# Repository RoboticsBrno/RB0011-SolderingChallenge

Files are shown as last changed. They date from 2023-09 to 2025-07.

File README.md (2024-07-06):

# RB0011 Soldering Challenge

<p align="center">


</p>

Solving the SMD soldering challenge is a great way to learn how to solder SMD components.

<div align="center">
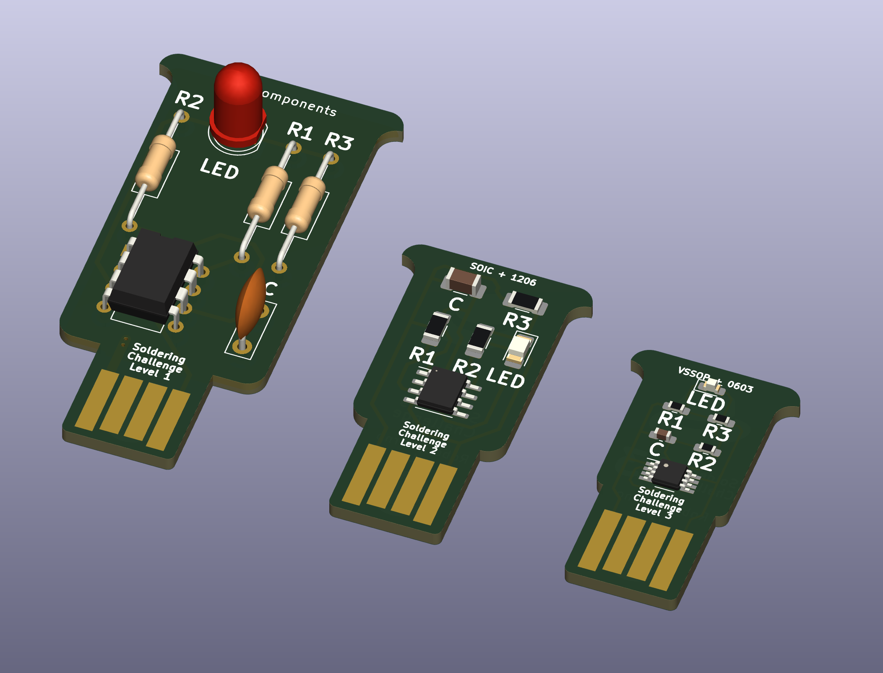
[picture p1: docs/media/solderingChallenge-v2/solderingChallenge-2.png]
    
</div>

[Soldering Instructions](assembly/index.md){ .md-button .md-button--primary }

The challenge is to solder all the components on the PCB in the shortest time possible.

## Levels
- Level 1 - THT components
- Level 2 - SMD 1206 components
- Level 3 - SMD 0603 components
<!-- - Level 4 - SMD 0402 components (PCB is not complete)
- Level 5 - SMD 0201 components (PCB is not complete) -->

If you manage to plug in all the components correctly, the LED will flash at about 2 Hz when plugged into the USB port.

<div align="center">
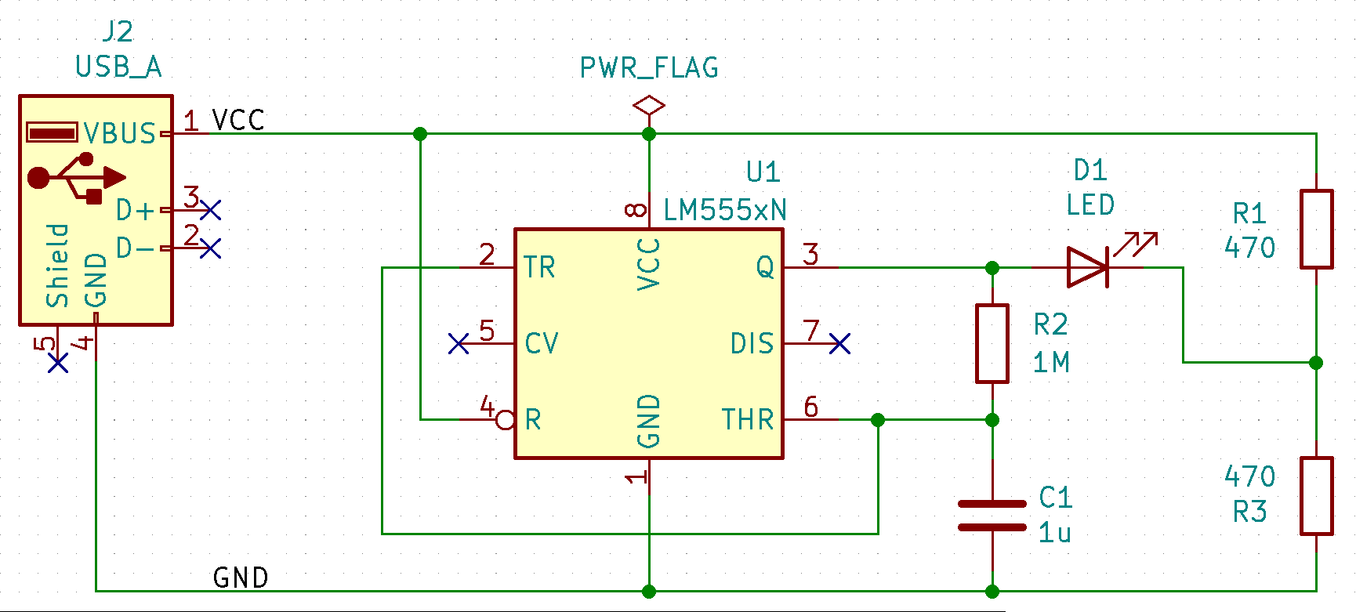
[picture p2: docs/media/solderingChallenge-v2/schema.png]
    
</div>

!!! info "Attention, L2 has swapped resistor R1 and R2"

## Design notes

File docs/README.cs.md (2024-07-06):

# RB0011 Pájecí výzva

<p align="center">


</p>

Pájecí challenge je skvělý způsob jak se naučit pájet SMD součástky.

<div align="center">
    
</div>

[Návod na pájení](assembly/index.md){ .md-button .md-button--primary }

Pájecí výzva spočívá v zapájení všech součástek na DPS v co nejkratším čase.

## Úrovně
- Level 1 - THT součástky
- Level 2 - SMD 1206 součástky
- Level 3 - SMD 0603 součástky
<!-- - Level 4 - SMD 0402 součástky
- Level 5 - SMD 0201 součástky -->

Pokud se ti podaří správně zapájet všechny součástky, tak po zapojení do USB portu začne LED blikat s frekvencí cca 2 Hz.

<div align="center">
    
</div>

!!! info "Pozor, L2 má prohozený rezistor R1 a R2"

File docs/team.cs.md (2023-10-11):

# Kdo za tím stojí

<script src="https://kit.fontawesome.com/5b4ac9752d.js" crossorigin="anonymous"></script>

Robotárna je unikátním spojením technické dílny a volnočasového vzdělávacího centra.
Zasazujeme se o vystavení našich žáků technickým a fyzikálním principům, což umožňuje efektivní tvorbu myšlenkových struktur a pomáhá s jejich rozvojem jak v oblasti techniky, tak v oblasti komunikace.

<div>
	<a href="https://robotickytabor.cz/" target="_blank">
		
	</a>
	<a href="https://robotka.robotickytabor.cz/" target="_blank">
	
	</a>
	<a href="https://roboruka.robotickytabor.cz/" target="_blank">
		
	</a>
</div>

Věříme, že dosažení vysokých cílů je možné skrze práci na mnoha úrovních abstrakce.
V rámci našich projektů si vyvíjíme vlastní mechanické součásti, elektorniku, firmware a software. I přesto jsou projekty koncipovány tak, aby byly přístupné i pro děti a začátečníky.
Naší misí je **vzbuzování zájmu mládeže o pochopení techniky tím, že je vystavujeme pokročilým systémům, které jsou však stále v jejich dosahu**.

Každý rok organizujeme [Robotický tábor](https://robotickytabor.cz/) s mnoha poutavými aktivitami. Programem tábora je také výroba fyzického zařízení, které je třeba smontovat, zapájet a naprogramovat.
Během školního roku naši žáci navštěvují volnočasové kroužky zaměřující se na stavění modelů, mechaniku, elektroniku a programování.
Jsme přesvědčeni, že naše aktivity jsou důležité pro doplnění veřejného vzdělávacího systému v oblasti techniky a poskytnutí mládeži více možností rozvoje.

<!-- <div align="center">
<a href="https://helceletka.cz/robotarna/"><button>Helceletka&nbsp;&nbsp;&nbsp;</button></a>
<a href="https://robotickytabor.cz/"><button>RoboCamp&nbsp;&nbsp;&nbsp;</button></a>
<a href="https://www.instagram.com/_robotarna_/"><button>Instagram&nbsp;&nbsp;&nbsp;</button></a>
<a href="https://www.facebook.com/robotarna"><button>Facebook&nbsp;&nbsp;&nbsp;</button></a>
<a href="https://www.youtube.com/@robotikabrno-robotarnaasps2392"><button>YouTube&nbsp;&nbsp;&nbsp;</button></a>
<a href="https://twitter.com/RobotikaBrno"><button>Twitter&nbsp;&nbsp;</button></a>

</div> -->

## Náš tým

<table style="width: 100%; border: none;">
    <tr>
        <td style="width: 50%; vertical-align: top; border: none;">
            Renata Zemanová's photo
        </td>
        <td style="width: 50%; vertical-align: top; border: none;">
            <h2> Renata Zemanová </h2>
            <p>Pro Renču je technika jedno velké kouzlo. I proto se jí věnuje a snaží se jí přijít co nejvíce na kloub. Baví ji pájení i většina rukodělných prací. Ráda své vědomosti předává dál, baví ji přemýšlet a nesnáší stereotypy. Je velmi společenská a přátelská. Bojí se výšek a přesto miluje hory a rozhledny a fascinují ji krásné výhledy do přírody. Hraje také na kytaru a zpívá ve sboru. Ráda by se někdy podívala na Island, do Norska nebo do Kanady. Na našem táboře je na pozici hlavní vedoucí.</p>
            <p style="font-size: 15px;">
                <i class="fas fa-envelope"></i> <a href="mailto:renata.zemanova@helceletka.cz">renata.zemanova@helceletka.cz</a><br>
                <i class="fab fa-github"></i> <a href="https://github.com/renata7zemanova" target="_blank">renata7zemanova</a><br>
            </p>
        </td>
    </tr>
</table>
<hr>

<table style="width: 100%; border: none;">
    <tr>
        <td style="width: 50%; vertical-align: top; border: none;">
            <h2> Jakub Andrýsek </h2>
            <p>Kuba je člověk pro všechno, rád pomůže všude tam, kde je třeba. Neodradí ho ani nestandardní situace a jde si vždy za svým cílem.  Studoval informatiku na gymnáziu Vídeňská a nyní pokračuje na FI MUNI v Brně. Nejčastěji ho najdete viset na skále, nebo sedět u počítače, kde vymýšlí nějaké nové projekty. U nás se věnuje hlavně programování a také 3D modelování v kroužku, který už několik let vede.</p>
            <p style="font-size: 15px;">
                <i class="fas fa-envelope"></i> <a href="mailto:email@kubaandrysek.cz">email@kubaandrysek.cz</a><br>
                <i class="fab fa-linkedin"></i> <a href="https://www.linkedin.com/in/jakub-andrysek/" target="_blank">in/jakub-andrysek</a><br>
                <i class="fab fa-github"></i> <a href="https://github.com/JakubAndrysek" target="_blank">JakubAndrysek</a><br>
                <i class="fas fa-globe"></i> <a href="https://kubaandrysek.cz/" target="_blank">kubaandrysek.cz</a>
            </p>
        </td>
        <td style="width: 50%; vertical-align: top; border: none;">
            Jakub Andrýsek's photo
        </td>
    </tr>
</table>
<hr>
<table style="width: 100%; border: none;">
    <tr>
        <td style="width: 50%; vertical-align: top; border: none;">
            Tomáš Vavrinec's photo
        </td>
        <td style="width: 50%; vertical-align: top; border: none;">
            <h2> Tomáš Vavrinec </h2>
            <p>Tom je člověk primárně pro elektroniku, přesto nepohrdne ani dobrou táborovou hrou nebo jinou kulišarnou. Když se pro něco nadchne nepřestane dokud neuzná dílo za hotové. Aktuálně je studentem ústavu mikroelektrotechniky na fakultě FEKT univerzity VUT a zároveň pracuje na vývoji měřících zařízení.  Bývá k vidění na nejrůznějších horách i za polárním kruhem, přesto že nejčastěji ho najdete v okolí technologického parku VUT, nebo u počítače či osciloskopu, jak se snaží zprovoznit hračky nejmenovanému programátorovi. U nás se zabývá návrhem elektroniky a mechaniky všeho druhu a spolu s Kubou Andrýskem vede kroužek 3D modelování a 3D tisku.</p>
            <p style="font-size: 15px;">
                <i class="fab fa-github"></i> <a href="https://github.com/TVavrinec" target="_blank">TVavrinec</a><br>
                <i class="fas fa-envelope"></i> <a href="mailto:tomas.vavrinec@helceletka.cz">tomas.vavrinec@helceletka.cz</a><br>
            </p>
        </td>
    </tr>
</table>

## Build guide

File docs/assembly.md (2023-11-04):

# Soldering Instructions

## How to Proceed

- **Always solder only one level at a time.**
- Take one component from the holder, solder it, and only after that take another one. (They are easy to mixup.)
- Once you have soldered everything, glue a padding underneath the USB connector.

!!! info "Important Information"
    - Start by soldering the integrated circuit. As last solder the LED.
        - Be mindful of the orientation of the integrated circuit. If you're unsure, ask the instructor.
	- Polarity usually matters with LEDs. However, on this board, you don't have to worry about polarity; the circuit is designed to be polarity-agnostic.

!!! danger "Work Safety"
	- The tip of the soldering iron is hot (~300 °C).
	- Always place the soldering iron back in its stand.
	- Keep your workspace tidy.
	- If you get burned, go and cool the burned area with water (do not use ice). Don't rub anything on the burned area.

## L1 - THT

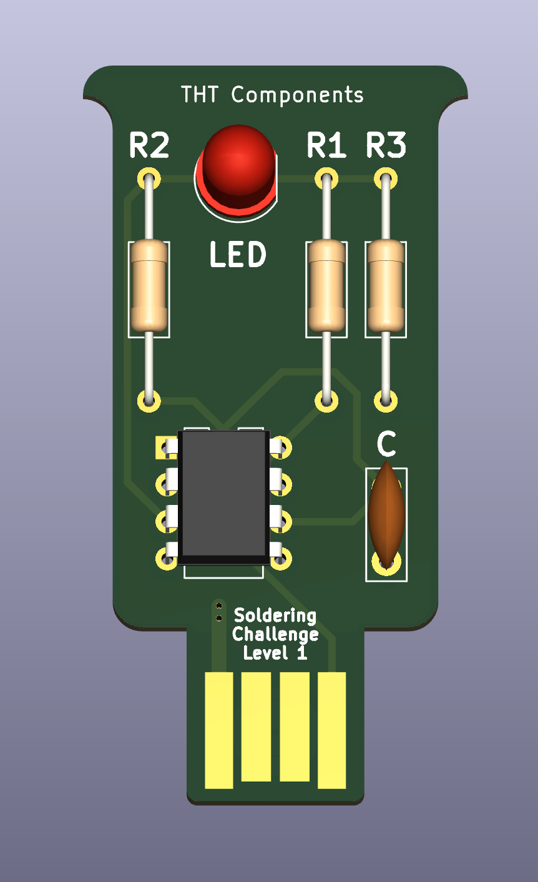
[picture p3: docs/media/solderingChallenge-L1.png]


## L2 - 1206
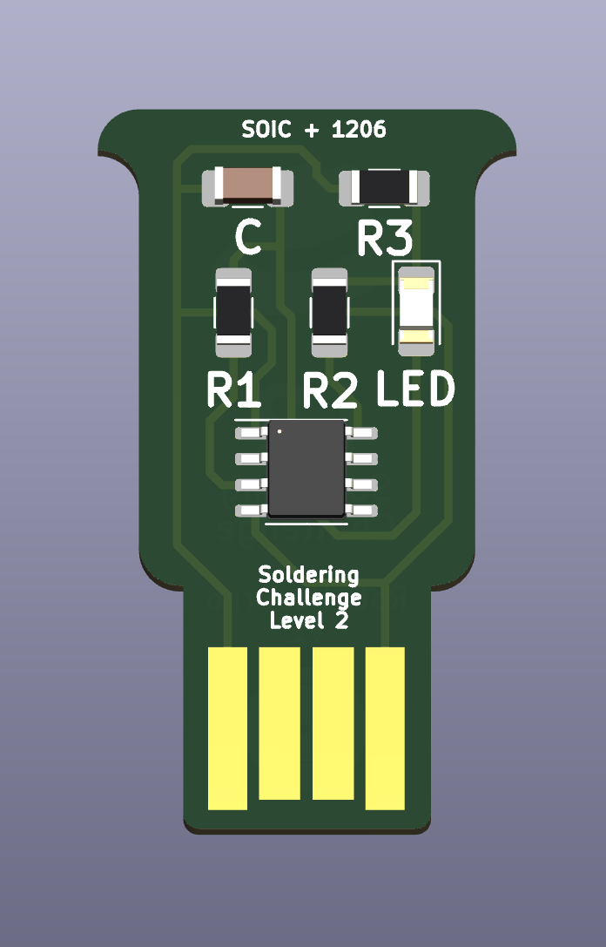
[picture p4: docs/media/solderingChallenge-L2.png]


!!! info "Note that L2 has the same resistors R2 and R3. R1 is different here"

## L3 - 0603
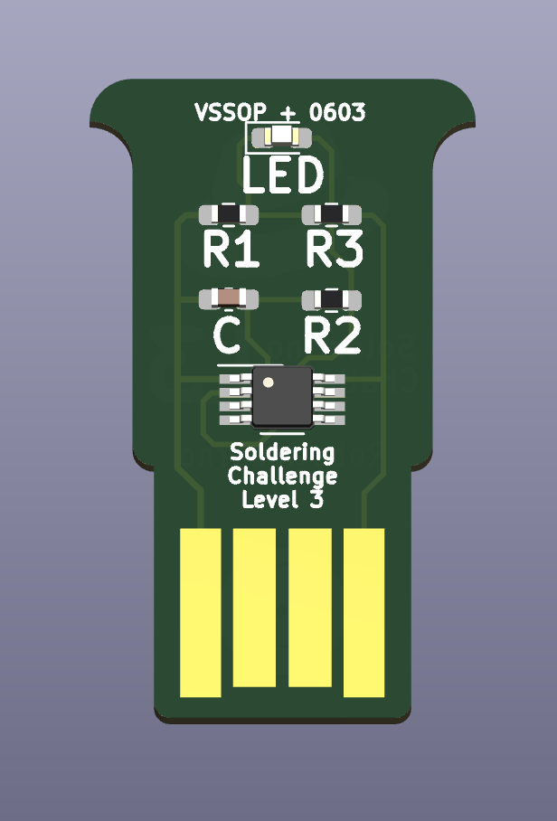
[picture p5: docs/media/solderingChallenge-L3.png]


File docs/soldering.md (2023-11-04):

# How to Solder

Soldering is a process in which we heat and join two (or more) components using flux and solder.

## Preparation
- **Sponge:** Wet the sponge before starting. After every soldered joint, first wipe the tip on the sponge and then place it in the holder.
- **Flux:** It aids in better solder wettability and helps create a conductive, smooth, and good-looking joint.
- **Soldering Station:**
    - **Transformer Soldering Iron:** It is larger and heavier.
    - **Micro-soldering Iron:** Heats continuously during operation, not only when the button is pressed, unlike the transformer soldering iron. The temperature is adjustable and regulated, preventing damage to the soldering tip.
        - Set the micro-soldering iron to a temperature of 300 °C.

## Types of Soldering

* **THT (Through-hole technology)** - soldering components with metal legs that are inserted through holes in the printed circuit board.
* **SMD (Surface-mount technology)** - soldering components with metal bands that are pasted onto the printed circuit board.

## How to Proceed
<figure markdown>
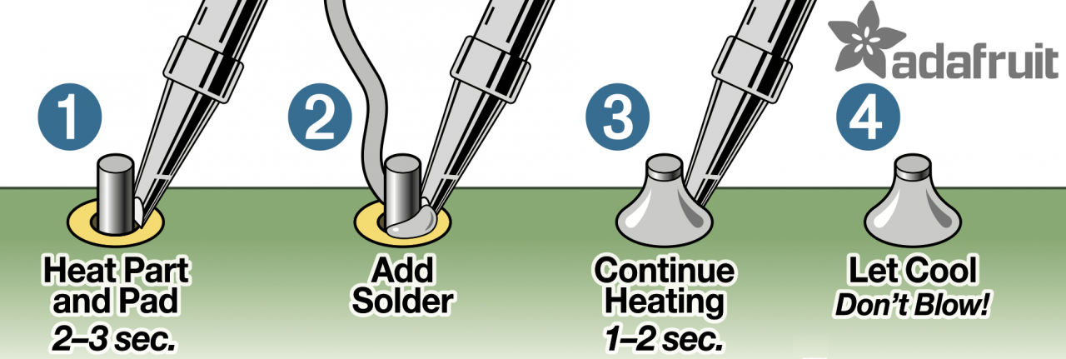
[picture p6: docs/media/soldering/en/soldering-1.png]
Soldering
  
  <figcaption markdown>Image 1: How to solder [source :octicons-link-external-16:](https://consolemods.org/wiki/Intro_to_Soldering)</figcaption>
</figure>

<figure markdown>
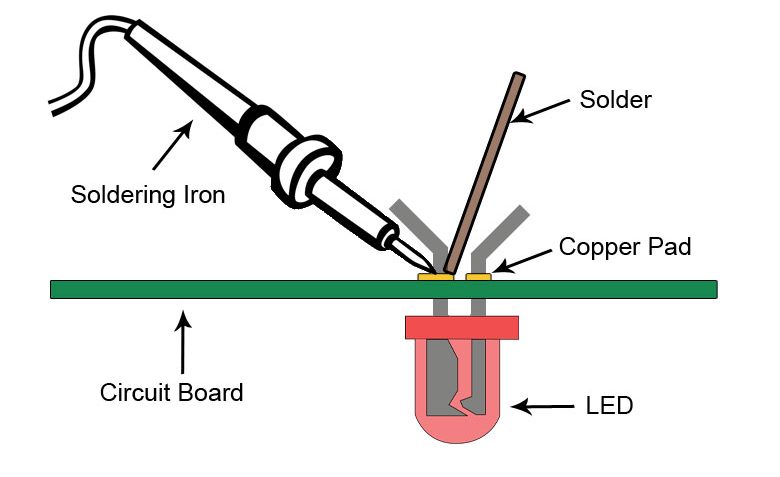
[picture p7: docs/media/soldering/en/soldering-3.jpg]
Soldering
  
  <figcaption markdown>Image 2: How to solder [source :octicons-link-external-16:](https://www.circuitspecialists.com/blog/how-to-soldering-correctly-soldering-101/)</figcaption>
</figure>

<figure markdown>
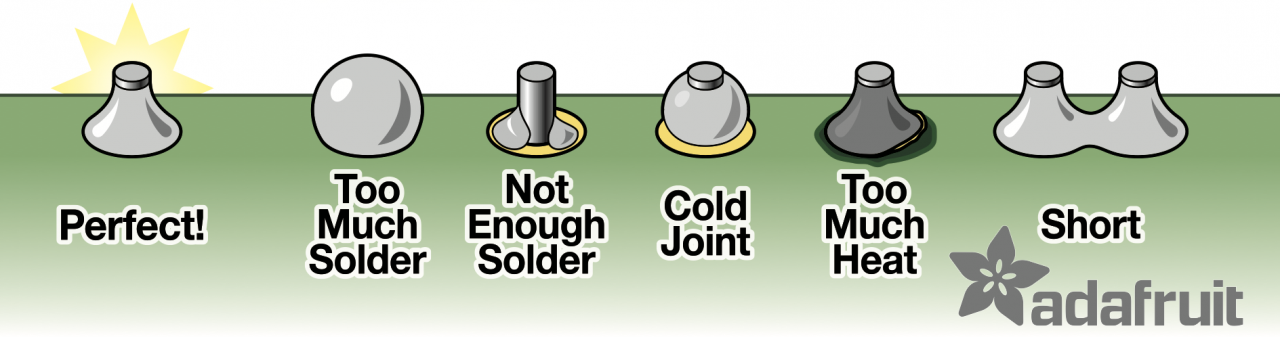
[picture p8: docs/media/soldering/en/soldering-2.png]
Soldering
  
  <figcaption markdown>Image 3: How it should look [source :octicons-link-external-16:](https://consolemods.org/wiki/Intro_to_Soldering)</figcaption>
</figure>

## Tutorials

### THT
type:video

### SMD - chip
type:video

### SMD
type:video

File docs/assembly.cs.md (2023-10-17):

# Osazovací návod

## Jak postupovat

- **Vždy pájej pouze jednu úroveň najednou.**
- Vždy si vezmi jednu součástku, tu zapájej a až pak pokračuj s další.
- Pak můžeš zapájet ostatní součástky.
- Jakmile máš zapájeno, nalep zespodu USB konektoru podložku.

!!! info "Důležité informace"
	- Začni připájením integrovaného obvodu.
    	- U integrovaného obvodu si pohlídej jeho orientaci. Pokud si nejsi jistý, zeptej se lektora.
  	- Jako poslední připájej LED
	- U LED běžně na polaritě záleží. Na této desce však polaritu řešit nemusíte, obvod je navržen tak, aby na polaritě nezáleželo.

!!! danger "Bezpečnost práce"
	- Hrot páječky je horký (~300 °C).
	- Páječku vždy odkládejte do stojanu.
	- Udržujte pořádek na pracovišti.
	- Když se popálíte, tak si běžte popálené místo zchladit vodou, případně ledem. Popálené místo ničím nemastěte.

## L1 - THT



## L2 - 1206


!!! info "Pozor, L2 má stejné rezistory R2 a R3. R1 je zde jiný"

## L3 - 0603


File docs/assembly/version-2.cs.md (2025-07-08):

# Osazovací návod - V2

Verze z roku 2023

## Jak postupovat

- **Vždy pájej pouze jednu úroveň najednou.**
- Vždy si vezmi jednu součástku, tu zapájej a až pak pokračuj s další.
- Pak můžeš zapájet ostatní součástky.
- Jakmile máš zapájeno, nalep zespodu USB konektoru podložku.

!!! info "Důležité informace"
	- Začni připájením integrovaného obvodu.
    	- U integrovaného obvodu si pohlídej jeho orientaci. Pokud si nejsi jistý, zeptej se lektora.
  	- Jako poslední připájej LED
	- U LED běžně na polaritě záleží. Na této desce však polaritu řešit nemusíte, obvod je navržen tak, aby na polaritě nezáleželo.

!!! danger "Bezpečnost práce"
	- Hrot páječky je horký (~300 °C).
	- Páječku vždy odkládejte do stojanu.
	- Udržujte pořádek na pracovišti.
	- Když se popálíte, tak si běžte popálené místo zchladit vodou, případně ledem. Popálené místo ničím nemastěte.

## L1 - THT

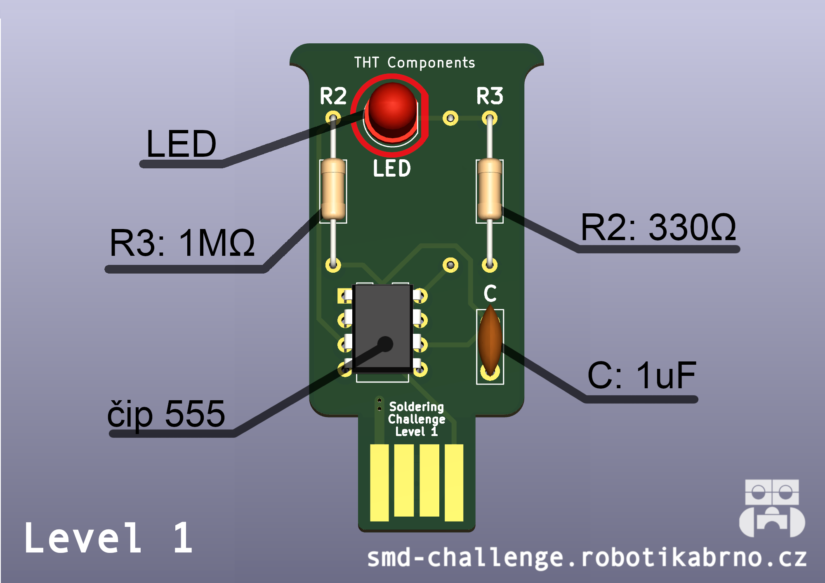
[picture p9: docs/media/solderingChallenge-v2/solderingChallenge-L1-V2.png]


## L2 - 1206
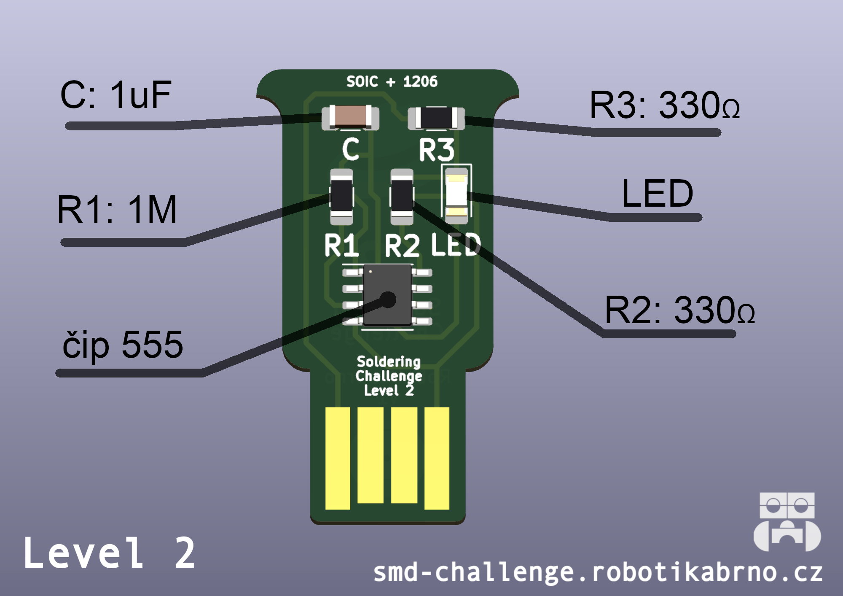
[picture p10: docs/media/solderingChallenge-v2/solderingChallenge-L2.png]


!!! info "Pozor, L2 má stejné rezistory R2 a R3. R1 je zde jiný"

## L3 - 0603
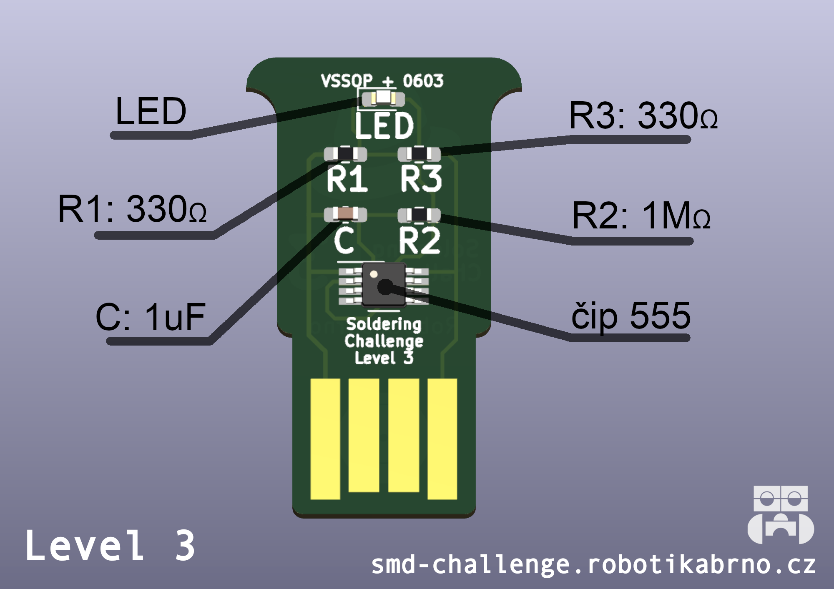
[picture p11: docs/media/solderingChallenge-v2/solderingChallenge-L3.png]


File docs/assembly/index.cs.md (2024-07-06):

# Osazovací návod

## Vyber si verzi

### Verze 1 - 2021
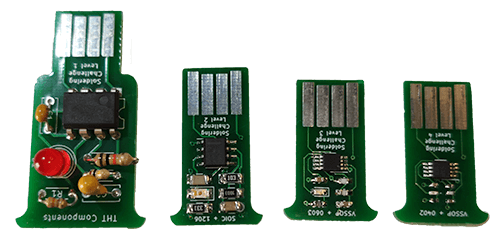
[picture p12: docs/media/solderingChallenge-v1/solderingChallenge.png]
Version 1


### Verze 2 - 2023
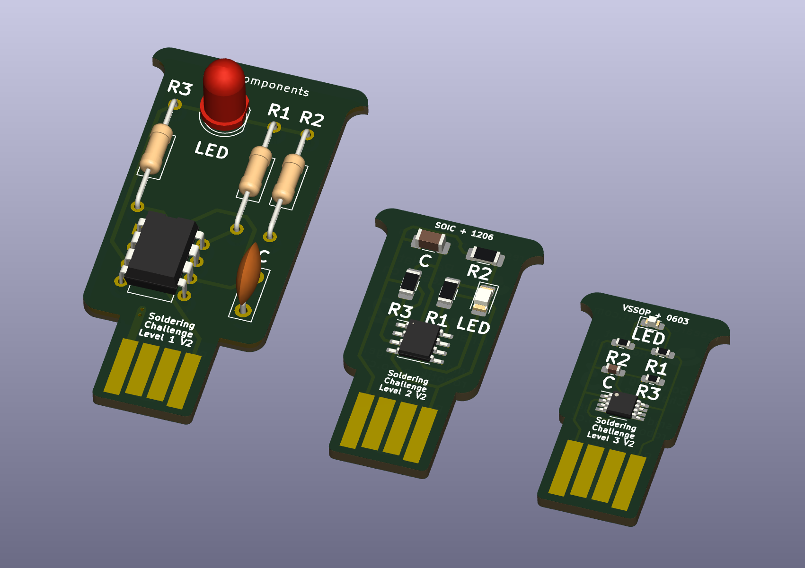
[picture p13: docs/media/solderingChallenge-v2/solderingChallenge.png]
Version 2


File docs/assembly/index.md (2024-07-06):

# Soldering Instructions

## Choose a version

### Version 1
Version 1

### Version 2
Version 2

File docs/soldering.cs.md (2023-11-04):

# Jak pájet

Pájení je proces, při kterém zahříváme a spojujeme dvě (nebo více) součástky za použití tavidla a cínu.

## Příprava
- **Houbička:** Před začátkem práce namočte houbičku. Po každém zapájeném spoji nejdříve otřete hrot o houbičku a až poté ji odložte do stojanu.
- **Tavidlo:** Slouží k lepší smáčivosti cínu a napomáhá vytvářet vodivý, hladký a hezký spoj.
- **Pájecí stanice:**
    - **Trafopájka:** Je větší a těžší.
    - **Mikropájka:** Hřeje po celou dobu spuštění, ne pouze po stisku tlačítka, jako u trafopájky. Teplota je nastavitelná a regulovaná, čímž se předchází poškozování pájecího hrotu.
        - Mikropájku nastav na teplotu 300 °C.

## Druhy pájení

* **THT (Through-hole technology)** - pájení součástek s kovovými nožičkami, které se prostrčí otvory v desce plošných spojů.
* **SMD (Surface-mount technology)** - pájení součástek s kovovými pásky, které se nalepí na desku plošných spojů.

## Jak postupovat
<figure markdown>
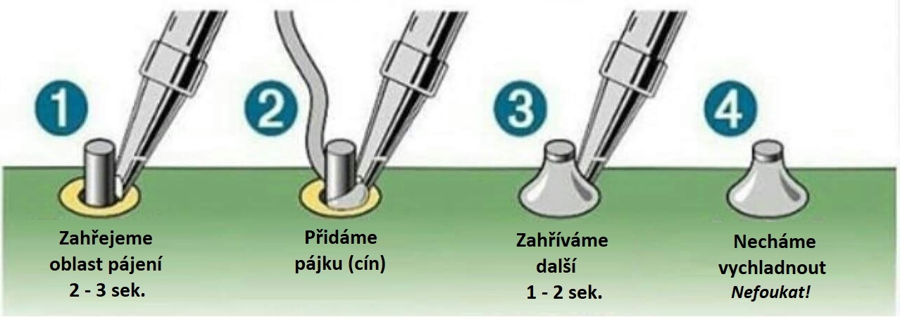
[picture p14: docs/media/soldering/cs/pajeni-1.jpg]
Pajeni
  
  <figcaption markdown>Obrázek 1: Jak pájet [zdroj :octicons-link-external-16:](https://kutiluv-zapisnik.cz/jak-spravne-pajet-elektronicke-soucastky)</figcaption>
</figure>

<figure markdown>
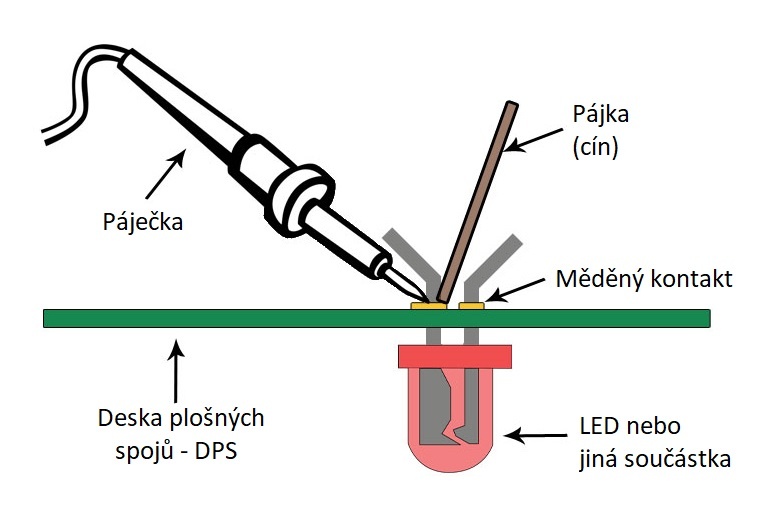
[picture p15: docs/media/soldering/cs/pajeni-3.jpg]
Pajeni
  
  <figcaption markdown>Obrázek 2: Jak pájet [zdroj :octicons-link-external-16:](https://kutiluv-zapisnik.cz/jak-spravne-pajet-elektronicke-soucastky)</figcaption>
</figure>

<figure markdown>
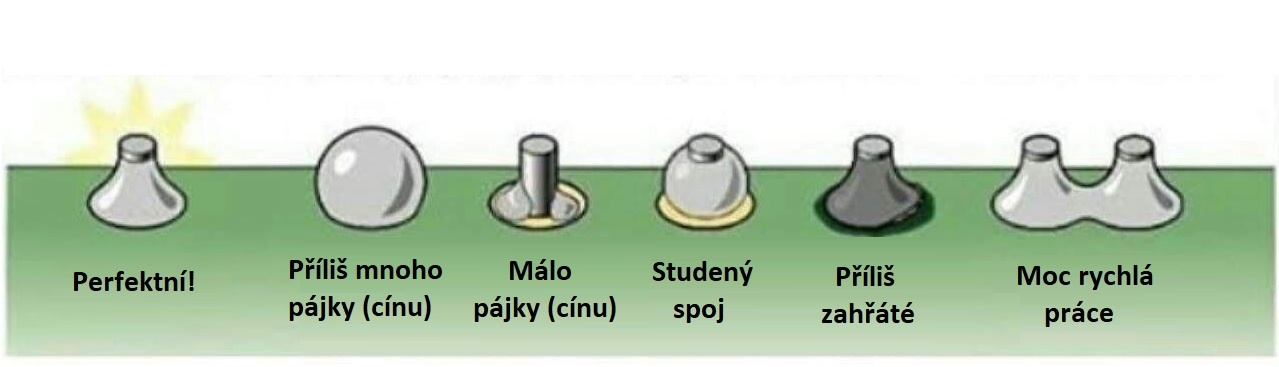
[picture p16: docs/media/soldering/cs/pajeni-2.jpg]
Pajeni
  
  <figcaption markdown>Obrázek 3: Jak to má vypadat [zdroj :octicons-link-external-16:](https://kutiluv-zapisnik.cz/jak-spravne-pajet-elektronicke-soucastky)</figcaption>
</figure>

## Tutoriály

### THT
type:video

### SMD - čip
type:video

### SMD
type:video

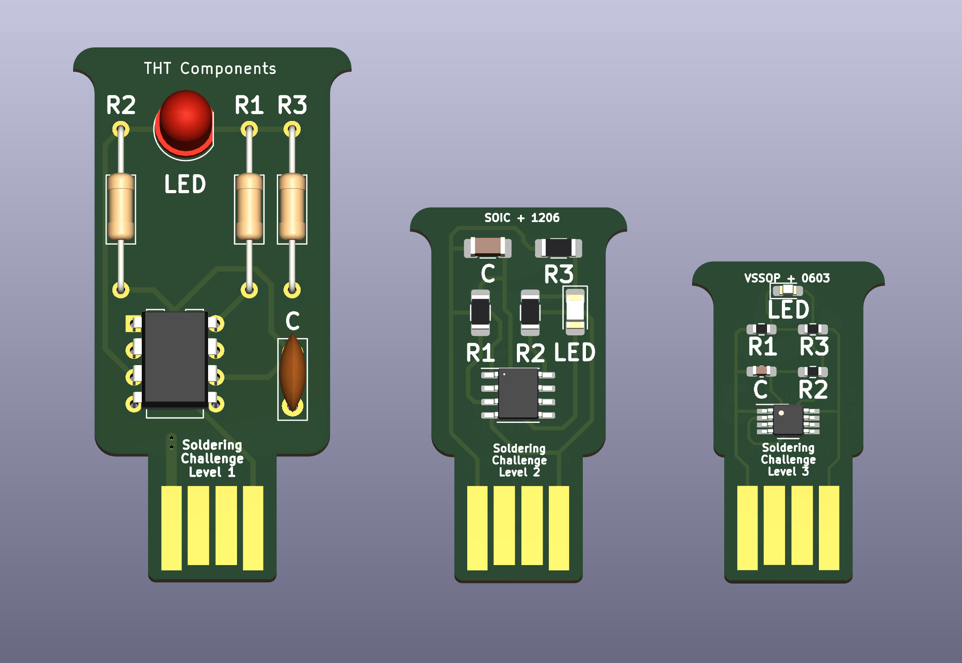
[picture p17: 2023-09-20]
docs/media/solderingChallenge-v2/solderingChallenge-1.png

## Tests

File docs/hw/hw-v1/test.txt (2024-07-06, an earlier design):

execve("/usr/local/bin/convert", ["convert", "-verbose", "-density", "300", "front.svg", "-verbose", "test.png"], 0x7fff8060d010 /* 69 vars */) = 0
brk(NULL)                               = 0x55ff3133f000
arch_prctl(0x3001 /* ARCH_??? */, 0x7fffaac9c600) = -1 EINVAL (Invalid argument)
access("/etc/ld.so.preload", R_OK)      = -1 ENOENT (No such file or directory)
openat(AT_FDCWD, "/etc/ld.so.cache", O_RDONLY|O_CLOEXEC) = 3
fstat(3, {st_mode=S_IFREG|0644, st_size=291406, ...}) = 0
mmap(NULL, 291406, PROT_READ, MAP_PRIVATE, 3, 0) = 0x7f10e980b000
close(3)                                = 0
openat(AT_FDCWD, "/usr/local/lib/libMagickCore-7.Q32HDRI.so.9", O_RDONLY|O_CLOEXEC) = 3
read(3, "\177ELF\2\1\1\0\0\0\0\0\0\0\0\0\3\0>\0\1\0\0\0\320\365\2\0\0\0\0\0"..., 832) = 832
fstat(3, {st_mode=S_IFREG|0755, st_size=3596808, ...}) = 0
mmap(NULL, 8192, PROT_READ|PROT_WRITE, MAP_PRIVATE|MAP_ANONYMOUS, -1, 0) = 0x7f10e9809000
mmap(NULL, 3526704, PROT_READ, MAP_PRIVATE|MAP_DENYWRITE, 3, 0) = 0x7f10e94ab000
mmap(0x7f10e94d2000, 2502656, PROT_READ|PROT_EXEC, MAP_PRIVATE|MAP_FIXED|MAP_DENYWRITE, 3, 0x27000) = 0x7f10e94d2000
mmap(0x7f10e9735000, 421888, PROT_READ, MAP_PRIVATE|MAP_FIXED|MAP_DENYWRITE, 3, 0x28a000) = 0x7f10e9735000
mmap(0x7f10e979c000, 319488, PROT_READ|PROT_WRITE, MAP_PRIVATE|MAP_FIXED|MAP_DENYWRITE, 3, 0x2f0000) = 0x7f10e979c000
mmap(0x7f10e97ea000, 122928, PROT_READ|PROT_WRITE, MAP_PRIVATE|MAP_FIXED|MAP_ANONYMOUS, -1, 0) = 0x7f10e97ea000
close(3)                                = 0
openat(AT_FDCWD, "/usr/local/lib/libMagickWand-7.Q32HDRI.so.9", O_RDONLY|O_CLOEXEC) = 3
read(3, "\177ELF\2\1\1\0\0\0\0\0\0\0\0\0\3\0>\0\1\0\0\0\0i\1\0\0\0\0\0"..., 832) = 832
fstat(3, {st_mode=S_IFREG|0755, st_size=1395328, ...}) = 0
mmap(NULL, 1290896, PROT_READ, MAP_PRIVATE|MAP_DENYWRITE, 3, 0) = 0x7f10e936f000
mmap(0x7f10e9381000, 995328, PROT_READ|PROT_EXEC, MAP_PRIVATE|MAP_FIXED|MAP_DENYWRITE, 3, 0x12000) = 0x7f10e9381000
mmap(0x7f10e9474000, 212992, PROT_READ, MAP_PRIVATE|MAP_FIXED|MAP_DENYWRITE, 3, 0x105000) = 0x7f10e9474000
mmap(0x7f10e94a8000, 12288, PROT_READ|PROT_WRITE, MAP_PRIVATE|MAP_FIXED|MAP_DENYWRITE, 3, 0x138000) = 0x7f10e94a8000
close(3)                                = 0
openat(AT_FDCWD, "/lib/x86_64-linux-gnu/libc.so.6", O_RDONLY|O_CLOEXEC) = 3
read(3, "\177ELF\2\1\1\3\0\0\0\0\0\0\0\0\3\0>\0\1\0\0\0\360q\2\0\0\0\0\0"..., 832) = 832
pread64(3, "\6\0\0\0\4\0\0\0@\0\0\0\0\0\0\0@\0\0\0\0\0\0\0@\0\0\0\0\0\0\0"..., 784, 64) = 784
pread64(3, "\4\0\0\0\20\0\0\0\5\0\0\0GNU\0\2\0\0\300\4\0\0\0\3\0\0\0\0\0\0\0", 32, 848) = 32
pread64(3, "\4\0\0\0\24\0\0\0\3\0\0\0GNU\0\t\233\222%\274\260\320\31\331\326\10\204\276X>\263"..., 68, 880) = 68
fstat(3, {st_mode=S_IFREG|0755, st_size=2029224, ...}) = 0
pread64(3, "\6\0\0\0\4\0\0\0@\0\0\0\0\0\0\0@\0\0\0\0\0\0\0@\0\0\0\0\0\0\0"..., 784, 64) = 784
pread64(3, "\4\0\0\0\20\0\0\0\5\0\0\0GNU\0\2\0\0\300\4\0\0\0\3\0\0\0\0\0\0\0", 32, 848) = 32
pread64(3, "\4\0\0\0\24\0\0\0\3\0\0\0GNU\0\t\233\222%\274\260\320\31\331\326\10\204\276X>\263"..., 68, 880) = 68
mmap(NULL, 2036952, PROT_READ, MAP_PRIVATE|MAP_DENYWRITE, 3, 0) = 0x7f10e917d000
mprotect(0x7f10e91a2000, 1847296, PROT_NONE) = 0
mmap(0x7f10e91a2000, 1540096, PROT_READ|PROT_EXEC, MAP_PRIVATE|MAP_FIXED|MAP_DENYWRITE, 3, 0x25000) = 0x7f10e91a2000
mmap(0x7f10e931a000, 303104, PROT_READ, MAP_PRIVATE|MAP_FIXED|MAP_DENYWRITE, 3, 0x19d000) = 0x7f10e931a000
mmap(0x7f10e9365000, 24576, PROT_READ|PROT_WRITE, MAP_PRIVATE|MAP_FIXED|MAP_DENYWRITE, 3, 0x1e7000) = 0x7f10e9365000
mmap(0x7f10e936b000, 13528, PROT_READ|PROT_WRITE, MAP_PRIVATE|MAP_FIXED|MAP_ANONYMOUS, -1, 0) = 0x7f10e936b000
close(3)                                = 0
openat(AT_FDCWD, "/lib/x86_64-linux-gnu/liblcms2.so.2", O_RDONLY|O_CLOEXEC) = 3
read(3, "\177ELF\2\1\1\0\0\0\0\0\0\0\0\0\3\0>\0\1\0\0\0\300\226\0\0\0\0\0\0"..., 832) = 832
fstat(3, {st_mode=S_IFREG|0644, st_size=365568, ...}) = 0
mmap(NULL, 369912, PROT_READ, MAP_PRIVATE|MAP_DENYWRITE, 3, 0) = 0x7f10e9122000
mprotect(0x7f10e912b000, 311296, PROT_NONE) = 0
mmap(0x7f10e912b000, 225280, PROT_READ|PROT_EXEC, MAP_PRIVATE|MAP_FIXED|MAP_DENYWRITE, 3, 0x9000) = 0x7f10e912b000
mmap(0x7f10e9162000, 81920, PROT_READ, MAP_PRIVATE|MAP_FIXED|MAP_DENYWRITE, 3, 0x40000) = 0x7f10e9162000
mmap(0x7f10e9177000, 20480, PROT_READ|PROT_WRITE, MAP_PRIVATE|MAP_FIXED|MAP_DENYWRITE, 3, 0x54000) = 0x7f10e9177000
mmap(0x7f10e917c000, 1272, PROT_READ|PROT_WRITE, MAP_PRIVATE|MAP_FIXED|MAP_ANONYMOUS, -1, 0) = 0x7f10e917c000
close(3)                                = 0
openat(AT_FDCWD, "/lib/x86_64-linux-gnu/libraqm.so.0", O_RDONLY|O_CLOEXEC) = 3
read(3, "\177ELF\2\1\1\0\0\0\0\0\0\0\0\0\3\0>\0\1\0\0\0\300$\0\0\0\0\0\0"..., 832) = 832
fstat(3, {st_mode=S_IFREG|0644, st_size=26616, ...}) = 0
mmap(NULL, 28688, PROT_READ, MAP_PRIVATE|MAP_DENYWRITE, 3, 0) = 0x7f10e911a000
mmap(0x7f10e911c000, 12288, PROT_READ|PROT_EXEC, MAP_PRIVATE|MAP_FIXED|MAP_DENYWRITE, 3, 0x2000) = 0x7f10e911c000
mmap(0x7f10e911f000, 4096, PROT_READ, MAP_PRIVATE|MAP_FIXED|MAP_DENYWRITE, 3, 0x5000) = 0x7f10e911f000
mmap(0x7f10e9120000, 8192, PROT_READ|PROT_WRITE, MAP_PRIVATE|MAP_FIXED|MAP_DENYWRITE, 3, 0x5000) = 0x7f10e9120000
close(3)                                = 0
openat(AT_FDCWD, "/lib/x86_64-linux-gnu/liblqr-1.so.0", O_RDONLY|O_CLOEXEC) = 3
read(3, "\177ELF\2\1\1\0\0\0\0\0\0\0\0\0\3\0>\0\1\0\0\0\20\33\0\0\0\0\0\0"..., 832) = 832
fstat(3, {st_mode=S_IFREG|0644, st_size=55304, ...}) = 0
mmap(NULL, 2150512, PROT_READ|PROT_EXEC, MAP_PRIVATE|MAP_DENYWRITE, 3, 0) = 0x7f10e8f0c000
mprotect(0x7f10e8f19000, 2093056, PROT_NONE) = 0
mmap(0x7f10e9118000, 8192, PROT_READ|PROT_WRITE, MAP_PRIVATE|MAP_FIXED|MAP_DENYWRITE, 3, 0xc000) = 0x7f10e9118000
close(3)                                = 0
openat(AT_FDCWD, "/lib/x86_64-linux-gnu/libfftw3.so.3", O_RDONLY|O_CLOEXEC) = 3
read(3, "\177ELF\2\1\1\0\0\0\0\0\0\0\0\0\3\0>\0\1\0\0\0\2402\2\0\0\0\0\0"..., 832) = 832
fstat(3, {st_mode=S_IFREG|0644, st_size=2115912, ...}) = 0
mmap(NULL, 8192, PROT_READ|PROT_WRITE, MAP_PRIVATE|MAP_ANONYMOUS, -1, 0) = 0x7f10e8f0a000
mmap(NULL, 2118792, PROT_READ, MAP_PRIVATE|MAP_DENYWRITE, 3, 0) = 0x7f10e8d04000
mmap(0x7f10e8d27000, 1720320, PROT_READ|PROT_EXEC, MAP_PRIVATE|MAP_FIXED|MAP_DENYWRITE, 3, 0x23000) = 0x7f10e8d27000
mmap(0x7f10e8ecb000, 184320, PROT_READ, MAP_PRIVATE|MAP_FIXED|MAP_DENYWRITE, 3, 0x1c7000) = 0x7f10e8ecb000
mmap(0x7f10e8ef8000, 73728, PROT_READ|PROT_WRITE, MAP_PRIVATE|MAP_FIXED|MAP_DENYWRITE, 3, 0x1f3000) = 0x7f10e8ef8000
close(3)                                = 0
openat(AT_FDCWD, "/lib/x86_64-linux-gnu/libxml2.so.2", O_RDONLY|O_CLOEXEC) = 3
read(3, "\177ELF\2\1\1\0\0\0\0\0\0\0\0\0\3\0>\0\1\0\0\0P\336\2\0\0\0\0\0"..., 832) = 832
fstat(3, {st_mode=S_IFREG|0644, st_size=1799408, ...}) = 0
mmap(NULL, 1806584, PROT_READ, MAP_PRIVATE|MAP_DENYWRITE, 3, 0) = 0x7f10e8b4a000
mmap(0x7f10e8b77000, 1220608, PROT_READ|PROT_EXEC, MAP_PRIVATE|MAP_FIXED|MAP_DENYWRITE, 3, 0x2d000) = 0x7f10e8b77000
mmap(0x7f10e8ca1000, 356352, PROT_READ, MAP_PRIVATE|MAP_FIXED|MAP_DENYWRITE, 3, 0x157000) = 0x7f10e8ca1000
mmap(0x7f10e8cf8000, 40960, PROT_READ|PROT_WRITE, MAP_PRIVATE|MAP_FIXED|MAP_DENYWRITE, 3, 0x1ad000) = 0x7f10e8cf8000
mmap(0x7f10e8d02000, 4344, PROT_READ|PROT_WRITE, MAP_PRIVATE|MAP_FIXED|MAP_ANONYMOUS, -1, 0) = 0x7f10e8d02000
close(3)                                = 0
openat(AT_FDCWD, "/lib/x86_64-linux-gnu/libfontconfig.so.1", O_RDONLY|O_CLOEXEC) = 3
read(3, "\177ELF\2\1\1\0\0\0\0\0\0\0\0\0\3\0>\0\1\0\0\0\300\177\0\0\0\0\0\0"..., 832) = 832
fstat(3, {st_mode=S_IFREG|0644, st_size=285840, ...}) = 0
mmap(NULL, 288392, PROT_READ, MAP_PRIVATE|MAP_DENYWRITE, 3, 0) = 0x7f10e8b03000
mmap(0x7f10e8b0a000, 151552, PROT_READ|PROT_EXEC, MAP_PRIVATE|MAP_FIXED|MAP_DENYWRITE, 3, 0x7000) = 0x7f10e8b0a000
mmap(0x7f10e8b2f000, 98304, PROT_READ, MAP_PRIVATE|MAP_FIXED|MAP_DENYWRITE, 3, 0x2c000) = 0x7f10e8b2f000
mmap(0x7f10e8b47000, 12288, PROT_READ|PROT_WRITE, MAP_PRIVATE|MAP_FIXED|MAP_DENYWRITE, 3, 0x43000) = 0x7f10e8b47000
close(3)                                = 0
openat(AT_FDCWD, "/lib/x86_64-linux-gnu/libfreetype.so.6", O_RDONLY|O_CLOEXEC) = 3
read(3, "\177ELF\2\1\1\0\0\0\0\0\0\0\0\0\3\0>\0\1\0\0\0\220\307\0\0\0\0\0\0"..., 832) = 832
fstat(3, {st_mode=S_IFREG|0644, st_size=776264, ...}) = 0
mmap(NULL, 778256, PROT_READ, MAP_PRIVATE|MAP_DENYWRITE, 3, 0) = 0x7f10e8a44000
mprotect(0x7f10e8a50000, 700416, PROT_NONE) = 0
mmap(0x7f10e8a50000, 524288, PROT_READ|PROT_EXEC, MAP_PRIVATE|MAP_FIXED|MAP_DENYWRITE, 3, 0xc000) = 0x7f10e8a50000
mmap(0x7f10e8ad0000, 172032, PROT_READ, MAP_PRIVATE|MAP_FIXED|MAP_DENYWRITE, 3, 0x8c000) = 0x7f10e8ad0000
mmap(0x7f10e8afb000, 32768, PROT_READ|PROT_WRITE, MAP_PRIVATE|MAP_FIXED|MAP_DENYWRITE, 3, 0xb6000) = 0x7f10e8afb000
close(3)                                = 0
openat(AT_FDCWD, "/lib/x86_64-linux-gnu/libXext.so.6", O_RDONLY|O_CLOEXEC) = 3
read(3, "\177ELF\2\1\1\0\0\0\0\0\0\0\0\0\3\0>\0\1\0\0\0\340E\0\0\0\0\0\0"..., 832) = 832
fstat(3, {st_mode=S_IFREG|0644, st_size=81600, ...}) = 0
mmap(NULL, 84152, PROT_READ, MAP_PRIVATE|MAP_DENYWRITE, 3, 0) = 0x7f10e8a2f000
mmap(0x7f10e8a33000, 45056, PROT_READ|PROT_EXEC, MAP_PRIVATE|MAP_FIXED|MAP_DENYWRITE, 3, 0x4000) = 0x7f10e8a33000
mmap(0x7f10e8a3e000, 16384, PROT_READ, MAP_PRIVATE|MAP_FIXED|MAP_DENYWRITE, 3, 0xf000) = 0x7f10e8a3e000
mmap(0x7f10e8a42000, 8192, PROT_READ|PROT_WRITE, MAP_PRIVATE|MAP_FIXED|MAP_DENYWRITE, 3, 0x12000) = 0x7f10e8a42000
close(3)                                = 0
openat(AT_FDCWD, "/lib/x86_64-linux-gnu/libX11.so.6", O_RDONLY|O_CLOEXEC) = 3
read(3, "\177ELF\2\1\1\0\0\0\0\0\0\0\0\0\3\0>\0\1\0\0\0\300\220\1\0\0\0\0\0"..., 832) = 832
fstat(3, {st_mode=S_IFREG|0644, st_size=1293928, ...}) = 0
mmap(NULL, 1297720, PROT_READ, MAP_PRIVATE|MAP_DENYWRITE, 3, 0) = 0x7f10e88f2000
mprotect(0x7f10e890a000, 1179648, PROT_NONE) = 0
mmap(0x7f10e890a000, 569344, PROT_READ|PROT_EXEC, MAP_PRIVATE|MAP_FIXED|MAP_DENYWRITE, 3, 0x18000) = 0x7f10e890a000
mmap(0x7f10e8995000, 606208, PROT_READ, MAP_PRIVATE|MAP_FIXED|MAP_DENYWRITE, 3, 0xa3000) = 0x7f10e8995000
mmap(0x7f10e8a2a000, 20480, PROT_READ|PROT_WRITE, MAP_PRIVATE|MAP_FIXED|MAP_DENYWRITE, 3, 0x137000) = 0x7f10e8a2a000
close(3)                                = 0
openat(AT_FDCWD, "/lib/x86_64-linux-gnu/libbz2.so.1.0", O_RDONLY|O_CLOEXEC) = 3
read(3, "\177ELF\2\1\1\0\0\0\0\0\0\0\0\0\3\0>\0\1\0\0\0@\"\0\0\0\0\0\0"..., 832) = 832
fstat(3, {st_mode=S_IFREG|0644, st_size=74848, ...}) = 0
mmap(NULL, 8192, PROT_READ|PROT_WRITE, MAP_PRIVATE|MAP_ANONYMOUS, -1, 0) = 0x7f10e88f0000
mmap(NULL, 76840, PROT_READ, MAP_PRIVATE|MAP_DENYWRITE, 3, 0) = 0x7f10e88dd000
mmap(0x7f10e88df000, 53248, PROT_READ|PROT_EXEC, MAP_PRIVATE|MAP_FIXED|MAP_DENYWRITE, 3, 0x2000) = 0x7f10e88df000
mmap(0x7f10e88ec000, 8192, PROT_READ, MAP_PRIVATE|MAP_FIXED|MAP_DENYWRITE, 3, 0xf000) = 0x7f10e88ec000
mmap(0x7f10e88ee000, 8192, PROT_READ|PROT_WRITE, MAP_PRIVATE|MAP_FIXED|MAP_DENYWRITE, 3, 0x10000) = 0x7f10e88ee000
close(3)                                = 0
openat(AT_FDCWD, "/lib/x86_64-linux-gnu/libz.so.1", O_RDONLY|O_CLOEXEC) = 3
read(3, "\177ELF\2\1\1\3\0\0\0\0\0\0\0\0\3\0>\0\1\0\0\0\200\"\0\0\0\0\0\0"..., 832) = 832
fstat(3, {st_mode=S_IFREG|0644, st_size=108936, ...}) = 0
mmap(NULL, 110776, PROT_READ, MAP_PRIVATE|MAP_DENYWRITE, 3, 0) = 0x7f10e88c1000
mprotect(0x7f10e88c3000, 98304, PROT_NONE) = 0
mmap(0x7f10e88c3000, 69632, PROT_READ|PROT_EXEC, MAP_PRIVATE|MAP_FIXED|MAP_DENYWRITE, 3, 0x2000) = 0x7f10e88c3000
mmap(0x7f10e88d4000, 24576, PROT_READ, MAP_PRIVATE|MAP_FIXED|MAP_DENYWRITE, 3, 0x13000) = 0x7f10e88d4000
mmap(0x7f10e88db000, 8192, PROT_READ|PROT_WRITE, MAP_PRIVATE|MAP_FIXED|MAP_DENYWRITE, 3, 0x19000) = 0x7f10e88db000
close(3)                                = 0
openat(AT_FDCWD, "/lib/x86_64-linux-gnu/libltdl.so.7", O_RDONLY|O_CLOEXEC) = 3
read(3, "\177ELF\2\1\1\0\0\0\0\0\0\0\0\0\3\0>\0\1\0\0\0\240$\0\0\0\0\0\0"..., 832) = 832
fstat(3, {st_mode=S_IFREG|0644, st_size=39368, ...}) = 0
mmap(NULL, 41376, PROT_READ, MAP_PRIVATE|MAP_DENYWRITE, 3, 0) = 0x7f10e88b6000
mmap(0x7f10e88b8000, 20480, PROT_READ|PROT_EXEC, MAP_PRIVATE|MAP_FIXED|MAP_DENYWRITE, 3, 0x2000) = 0x7f10e88b8000
mmap(0x7f10e88bd000, 8192, PROT_READ, MAP_PRIVATE|MAP_FIXED|MAP_DENYWRITE, 3, 0x7000) = 0x7f10e88bd000
mmap(0x7f10e88bf000, 8192, PROT_READ|PROT_WRITE, MAP_PRIVATE|MAP_FIXED|MAP_DENYWRITE, 3, 0x8000) = 0x7f10e88bf000
close(3)                                = 0
openat(AT_FDCWD, "/lib/x86_64-linux-gnu/libm.so.6", O_RDONLY|O_CLOEXEC) = 3
read(3, "\177ELF\2\1\1\3\0\0\0\0\0\0\0\0\3\0>\0\1\0\0\0\300\363\0\0\0\0\0\0"..., 832) = 832
fstat(3, {st_mode=S_IFREG|0644, st_size=1369352, ...}) = 0
mmap(NULL, 1368336, PROT_READ, MAP_PRIVATE|MAP_DENYWRITE, 3, 0) = 0x7f10e8767000
mmap(0x7f10e8776000, 684032, PROT_READ|PROT_EXEC, MAP_PRIVATE|MAP_FIXED|MAP_DENYWRITE, 3, 0xf000) = 0x7f10e8776000
mmap(0x7f10e881d000, 618496, PROT_READ, MAP_PRIVATE|MAP_FIXED|MAP_DENYWRITE, 3, 0xb6000) = 0x7f10e881d000
mmap(0x7f10e88b4000, 8192, PROT_READ|PROT_WRITE, MAP_PRIVATE|MAP_FIXED|MAP_DENYWRITE, 3, 0x14c000) = 0x7f10e88b4000
close(3)                                = 0
openat(AT_FDCWD, "/lib/x86_64-linux-gnu/libjemalloc.so.2", O_RDONLY|O_CLOEXEC) = 3
read(3, "\177ELF\2\1\1\0\0\0\0\0\0\0\0\0\3\0>\0\1\0\0\0\0y\0\0\0\0\0\0"..., 832) = 832
fstat(3, {st_mode=S_IFREG|0644, st_size=744776, ...}) = 0
mmap(NULL, 2994480, PROT_READ, MAP_PRIVATE|MAP_DENYWRITE, 3, 0) = 0x7f10e848b000
mprotect(0x7f10e8492000, 696320, PROT_NONE) = 0
mmap(0x7f10e8492000, 626688, PROT_READ|PROT_EXEC, MAP_PRIVATE|MAP_FIXED|MAP_DENYWRITE, 3, 0x7000) = 0x7f10e8492000
mmap(0x7f10e852b000, 65536, PROT_READ, MAP_PRIVATE|MAP_FIXED|MAP_DENYWRITE, 3, 0xa0000) = 0x7f10e852b000
mmap(0x7f10e853c000, 24576, PROT_READ|PROT_WRITE, MAP_PRIVATE|MAP_FIXED|MAP_DENYWRITE, 3, 0xb0000) = 0x7f10e853c000
mmap(0x7f10e8542000, 2244912, PROT_READ|PROT_WRITE, MAP_PRIVATE|MAP_FIXED|MAP_ANONYMOUS, -1, 0) = 0x7f10e8542000
close(3)                                = 0
openat(AT_FDCWD, "/lib/x86_64-linux-gnu/libpthread.so.0", O_RDONLY|O_CLOEXEC) = 3
read(3, "\177ELF\2\1\1\0\0\0\0\0\0\0\0\0\3\0>\0\1\0\0\0\220\201\0\0\0\0\0\0"..., 832) = 832
pread64(3, "\4\0\0\0\24\0\0\0\3\0\0\0GNU\0\345Ga\367\265T\320\374\301V)Yf]\223\337"..., 68, 824) = 68
fstat(3, {st_mode=S_IFREG|0755, st_size=157224, ...}) = 0
pread64(3, "\4\0\0\0\24\0\0\0\3\0\0\0GNU\0\345Ga\367\265T\320\374\301V)Yf]\223\337"..., 68, 824) = 68
mmap(NULL, 140408, PROT_READ, MAP_PRIVATE|MAP_DENYWRITE, 3, 0) = 0x7f10e8468000
mmap(0x7f10e846f000, 69632, PROT_READ|PROT_EXEC, MAP_PRIVATE|MAP_FIXED|MAP_DENYWRITE, 3, 0x7000) = 0x7f10e846f000
mmap(0x7f10e8480000, 20480, PROT_READ, MAP_PRIVATE|MAP_FIXED|MAP_DENYWRITE, 3, 0x18000) = 0x7f10e8480000
mmap(0x7f10e8485000, 8192, PROT_READ|PROT_WRITE, MAP_PRIVATE|MAP_FIXED|MAP_DENYWRITE, 3, 0x1c000) = 0x7f10e8485000
mmap(0x7f10e8487000, 13432, PROT_READ|PROT_WRITE, MAP_PRIVATE|MAP_FIXED|MAP_ANONYMOUS, -1, 0) = 0x7f10e8487000
close(3)                                = 0
openat(AT_FDCWD, "/lib/x86_64-linux-gnu/libgomp.so.1", O_RDONLY|O_CLOEXEC) = 3
read(3, "\177ELF\2\1\1\0\0\0\0\0\0\0\0\0\3\0>\0\1\0\0\0\320\226\0\0\0\0\0\0"..., 832) = 832
fstat(3, {st_mode=S_IFREG|0644, st_size=265856, ...}) = 0
mmap(NULL, 8192, PROT_READ|PROT_WRITE, MAP_PRIVATE|MAP_ANONYMOUS, -1, 0) = 0x7f10e8466000
mmap(NULL, 268592, PROT_READ, MAP_PRIVATE|MAP_DENYWRITE, 3, 0) = 0x7f10e8424000
mmap(0x7f10e842d000, 176128, PROT_READ|PROT_EXEC, MAP_PRIVATE|MAP_FIXED|MAP_DENYWRITE, 3, 0x9000) = 0x7f10e842d000
mmap(0x7f10e8458000, 49152, PROT_READ, MAP_PRIVATE|MAP_FIXED|MAP_DENYWRITE, 3, 0x34000) = 0x7f10e8458000
mmap(0x7f10e8464000, 8192, PROT_READ|PROT_WRITE, MAP_PRIVATE|MAP_FIXED|MAP_DENYWRITE, 3, 0x3f000) = 0x7f10e8464000
close(3)                                = 0
openat(AT_FDCWD, "/lib/x86_64-linux-gnu/libgcc_s.so.1", O_RDONLY|O_CLOEXEC) = 3
read(3, "\177ELF\2\1\1\0\0\0\0\0\0\0\0\0\3\0>\0\1\0\0\0\3405\0\0\0\0\0\0"..., 832) = 832
fstat(3, {st_mode=S_IFREG|0644, st_size=104984, ...}) = 0
mmap(NULL, 107592, PROT_READ, MAP_PRIVATE|MAP_DENYWRITE, 3, 0) = 0x7f10e8409000
mmap(0x7f10e840c000, 73728, PROT_READ|PROT_EXEC, MAP_PRIVATE|MAP_FIXED|MAP_DENYWRITE, 3, 0x3000) = 0x7f10e840c000
mmap(0x7f10e841e000, 16384, PROT_READ, MAP_PRIVATE|MAP_FIXED|MAP_DENYWRITE, 3, 0x15000) = 0x7f10e841e000
mmap(0x7f10e8422000, 8192, PROT_READ|PROT_WRITE, MAP_PRIVATE|MAP_FIXED|MAP_DENYWRITE, 3, 0x18000) = 0x7f10e8422000
close(3)                                = 0
openat(AT_FDCWD, "/lib/x86_64-linux-gnu/libharfbuzz.so.0", O_RDONLY|O_CLOEXEC) = 3
read(3, "\177ELF\2\1\1\0\0\0\0\0\0\0\0\0\3\0>\0\1\0\0\0p\234\0\0\0\0\0\0"..., 832) = 832
fstat(3, {st_mode=S_IFREG|0644, st_size=1065824, ...}) = 0
mmap(NULL, 1068256, PROT_READ, MAP_PRIVATE|MAP_DENYWRITE, 3, 0) = 0x7f10e8304000
mprotect(0x7f10e830d000, 1024000, PROT_NONE) = 0
mmap(0x7f10e830d000, 819200, PROT_READ|PROT_EXEC, MAP_PRIVATE|MAP_FIXED|MAP_DENYWRITE, 3, 0x9000) = 0x7f10e830d000
mmap(0x7f10e83d5000, 200704, PROT_READ, MAP_PRIVATE|MAP_FIXED|MAP_DENYWRITE, 3, 0xd1000) = 0x7f10e83d5000
mmap(0x7f10e8407000, 8192, PROT_READ|PROT_WRITE, MAP_PRIVATE|MAP_FIXED|MAP_DENYWRITE, 3, 0x102000) = 0x7f10e8407000
close(3)                                = 0
openat(AT_FDCWD, "/lib/x86_64-linux-gnu/libfribidi.so.0", O_RDONLY|O_CLOEXEC) = 3
read(3, "\177ELF\2\1\1\0\0\0\0\0\0\0\0\0\3\0>\0\1\0\0\0\0!\0\0\0\0\0\0"..., 832) = 832
fstat(3, {st_mode=S_IFREG|0644, st_size=112960, ...}) = 0
mmap(NULL, 114904, PROT_READ, MAP_PRIVATE|MAP_DENYWRITE, 3, 0) = 0x7f10e82e7000
mmap(0x7f10e82e9000, 16384, PROT_READ|PROT_EXEC, MAP_PRIVATE|MAP_FIXED|MAP_DENYWRITE, 3, 0x2000) = 0x7f10e82e9000
mmap(0x7f10e82ed000, 86016, PROT_READ, MAP_PRIVATE|MAP_FIXED|MAP_DENYWRITE, 3, 0x6000) = 0x7f10e82ed000
mmap(0x7f10e8302000, 8192, PROT_READ|PROT_WRITE, MAP_PRIVATE|MAP_FIXED|MAP_DENYWRITE, 3, 0x1a000) = 0x7f10e8302000
close(3)                                = 0
openat(AT_FDCWD, "/lib/x86_64-linux-gnu/libglib-2.0.so.0", O_RDONLY|O_CLOEXEC) = 3
read(3, "\177ELF\2\1\1\0\0\0\0\0\0\0\0\0\3\0>\0\1\0\0\0 \333\1\0\0\0\0\0"..., 832) = 832
fstat(3, {st_mode=S_IFREG|0644, st_size=1207920, ...}) = 0
mmap(NULL, 1212872, PROT_READ, MAP_PRIVATE|MAP_DENYWRITE, 3, 0) = 0x7f10e81be000
mmap(0x7f10e81da000, 540672, PROT_READ|PROT_EXEC, MAP_PRIVATE|MAP_FIXED|MAP_DENYWRITE, 3, 0x1c000) = 0x7f10e81da000
mmap(0x7f10e825e000, 548864, PROT_READ, MAP_PRIVATE|MAP_FIXED|MAP_DENYWRITE, 3, 0xa0000) = 0x7f10e825e000
mmap(0x7f10e82e4000, 8192, PROT_READ|PROT_WRITE, MAP_PRIVATE|MAP_FIXED|MAP_DENYWRITE, 3, 0x125000) = 0x7f10e82e4000
mmap(0x7f10e82e6000, 456, PROT_READ|PROT_WRITE, MAP_PRIVATE|MAP_FIXED|MAP_ANONYMOUS, -1, 0) = 0x7f10e82e6000
close(3)                                = 0
openat(AT_FDCWD, "/lib/x86_64-linux-gnu/libdl.so.2", O_RDONLY|O_CLOEXEC) = 3
read(3, "\177ELF\2\1\1\0\0\0\0\0\0\0\0\0\3\0>\0\1\0\0\0 \22\0\0\0\0\0\0"..., 832) = 832
fstat(3, {st_mode=S_IFREG|0644, st_size=18816, ...}) = 0
mmap(NULL, 8192, PROT_READ|PROT_WRITE, MAP_PRIVATE|MAP_ANONYMOUS, -1, 0) = 0x7f10e81bc000
mmap(NULL, 20752, PROT_READ, MAP_PRIVATE|MAP_DENYWRITE, 3, 0) = 0x7f10e81b6000
mmap(0x7f10e81b7000, 8192, PROT_READ|PROT_EXEC, MAP_PRIVATE|MAP_FIXED|MAP_DENYWRITE, 3, 0x1000) = 0x7f10e81b7000
mmap(0x7f10e81b9000, 4096, PROT_READ, MAP_PRIVATE|MAP_FIXED|MAP_DENYWRITE, 3, 0x3000) = 0x7f10e81b9000
mmap(0x7f10e81ba000, 8192, PROT_READ|PROT_WRITE, MAP_PRIVATE|MAP_FIXED|MAP_DENYWRITE, 3, 0x3000) = 0x7f10e81ba000
close(3)                                = 0
openat(AT_FDCWD, "/lib/x86_64-linux-gnu/libicuuc.so.66", O_RDONLY|O_CLOEXEC) = 3
read(3, "\177ELF\2\1\1\0\0\0\0\0\0\0\0\0\3\0>\0\1\0\0\0 Y\6\0\0\0\0\0"..., 832) = 832
fstat(3, {st_mode=S_IFREG|0644, st_size=1976648, ...}) = 0
mmap(NULL, 1987008, PROT_READ, MAP_PRIVATE|MAP_DENYWRITE, 3, 0) = 0x7f10e7fd0000
mprotect(0x7f10e8035000, 1490944, PROT_NONE) = 0
mmap(0x7f10e8035000, 937984, PROT_READ|PROT_EXEC, MAP_PRIVATE|MAP_FIXED|MAP_DENYWRITE, 3, 0x65000) = 0x7f10e8035000
mmap(0x7f10e811a000, 548864, PROT_READ, MAP_PRIVATE|MAP_FIXED|MAP_DENYWRITE, 3, 0x14a000) = 0x7f10e811a000
mmap(0x7f10e81a1000, 77824, PROT_READ|PROT_WRITE, MAP_PRIVATE|MAP_FIXED|MAP_DENYWRITE, 3, 0x1d0000) = 0x7f10e81a1000
mmap(0x7f10e81b4000, 4544, PROT_READ|PROT_WRITE, MAP_PRIVATE|MAP_FIXED|MAP_ANONYMOUS, -1, 0) = 0x7f10e81b4000
close(3)                                = 0
openat(AT_FDCWD, "/lib/x86_64-linux-gnu/liblzma.so.5", O_RDONLY|O_CLOEXEC) = 3
read(3, "\177ELF\2\1\1\0\0\0\0\0\0\0\0\0\3\0>\0\1\0\0\0\3003\0\0\0\0\0\0"..., 832) = 832
fstat(3, {st_mode=S_IFREG|0644, st_size=162264, ...}) = 0
mmap(NULL, 164104, PROT_READ, MAP_PRIVATE|MAP_DENYWRITE, 3, 0) = 0x7f10e7fa7000
mprotect(0x7f10e7faa000, 147456, PROT_NONE) = 0
mmap(0x7f10e7faa000, 98304, PROT_READ|PROT_EXEC, MAP_PRIVATE|MAP_FIXED|MAP_DENYWRITE, 3, 0x3000) = 0x7f10e7faa000
mmap(0x7f10e7fc2000, 45056, PROT_READ, MAP_PRIVATE|MAP_FIXED|MAP_DENYWRITE, 3, 0x1b000) = 0x7f10e7fc2000
mmap(0x7f10e7fce000, 8192, PROT_READ|PROT_WRITE, MAP_PRIVATE|MAP_FIXED|MAP_DENYWRITE, 3, 0x26000) = 0x7f10e7fce000
close(3)                                = 0
openat(AT_FDCWD, "/lib/x86_64-linux-gnu/libexpat.so.1", O_RDONLY|O_CLOEXEC) = 3
read(3, "\177ELF\2\1\1\0\0\0\0\0\0\0\0\0\3\0>\0\1\0\0\0000B\0\0\0\0\0\0"..., 832) = 832
fstat(3, {st_mode=S_IFREG|0644, st_size=182560, ...}) = 0
mmap(NULL, 184480, PROT_READ, MAP_PRIVATE|MAP_DENYWRITE, 3, 0) = 0x7f10e7f79000
mprotect(0x7f10e7f7d000, 159744, PROT_NONE) = 0
mmap(0x7f10e7f7d000, 114688, PROT_READ|PROT_EXEC, MAP_PRIVATE|MAP_FIXED|MAP_DENYWRITE, 3, 0x4000) = 0x7f10e7f7d000
mmap(0x7f10e7f99000, 40960, PROT_READ, MAP_PRIVATE|MAP_FIXED|MAP_DENYWRITE, 3, 0x20000) = 0x7f10e7f99000
mmap(0x7f10e7fa4000, 12288, PROT_READ|PROT_WRITE, MAP_PRIVATE|MAP_FIXED|MAP_DENYWRITE, 3, 0x2a000) = 0x7f10e7fa4000
close(3)                                = 0
openat(AT_FDCWD, "/lib/x86_64-linux-gnu/libuuid.so.1", O_RDONLY|O_CLOEXEC) = 3
read(3, "\177ELF\2\1\1\0\0\0\0\0\0\0\0\0\3\0>\0\1\0\0\0\200%\0\0\0\0\0\0"..., 832) = 832
fstat(3, {st_mode=S_IFREG|0644, st_size=30936, ...}) = 0
mmap(NULL, 32792, PROT_READ, MAP_PRIVATE|MAP_DENYWRITE, 3, 0) = 0x7f10e7f70000
mmap(0x7f10e7f72000, 16384, PROT_READ|PROT_EXEC, MAP_PRIVATE|MAP_FIXED|MAP_DENYWRITE, 3, 0x2000) = 0x7f10e7f72000
mmap(0x7f10e7f76000, 4096, PROT_READ, MAP_PRIVATE|MAP_FIXED|MAP_DENYWRITE, 3, 0x6000) = 0x7f10e7f76000
mmap(0x7f10e7f77000, 8192, PROT_READ|PROT_WRITE, MAP_PRIVATE|MAP_FIXED|MAP_DENYWRITE, 3, 0x6000) = 0x7f10e7f77000
close(3)                                = 0
openat(AT_FDCWD, "/lib/x86_64-linux-gnu/libpng16.so.16", O_RDONLY|O_CLOEXEC) = 3
read(3, "\177ELF\2\1\1\0\0\0\0\0\0\0\0\0\3\0>\0\1\0\0\0\20U\0\0\0\0\0\0"..., 832) = 832
fstat(3, {st_mode=S_IFREG|0644, st_size=223304, ...}) = 0
mmap(NULL, 225296, PROT_READ, MAP_PRIVATE|MAP_DENYWRITE, 3, 0) = 0x7f10e7f38000
mmap(0x7f10e7f3d000, 151552, PROT_READ|PROT_EXEC, MAP_PRIVATE|MAP_FIXED|MAP_DENYWRITE, 3, 0x5000) = 0x7f10e7f3d000
mmap(0x7f10e7f62000, 49152, PROT_READ, MAP_PRIVATE|MAP_FIXED|MAP_DENYWRITE, 3, 0x2a000) = 0x7f10e7f62000
mmap(0x7f10e7f6e000, 8192, PROT_READ|PROT_WRITE, MAP_PRIVATE|MAP_FIXED|MAP_DENYWRITE, 3, 0x35000) = 0x7f10e7f6e000
close(3)                                = 0
openat(AT_FDCWD, "/lib/x86_64-linux-gnu/libxcb.so.1", O_RDONLY|O_CLOEXEC) = 3
read(3, "\177ELF\2\1\1\0\0\0\0\0\0\0\0\0\3\0>\0\1\0\0\0 \266\0\0\0\0\0\0"..., 832) = 832
fstat(3, {st_mode=S_IFREG|0644, st_size=166488, ...}) = 0
mmap(NULL, 8192, PROT_READ|PROT_WRITE, MAP_PRIVATE|MAP_ANONYMOUS, -1, 0) = 0x7f10e7f36000
mmap(NULL, 168616, PROT_READ, MAP_PRIVATE|MAP_DENYWRITE, 3, 0) = 0x7f10e7f0c000
mmap(0x7f10e7f17000, 81920, PROT_READ|PROT_EXEC, MAP_PRIVATE|MAP_FIXED|MAP_DENYWRITE, 3, 0xb000) = 0x7f10e7f17000
mmap(0x7f10e7f2b000, 36864, PROT_READ, MAP_PRIVATE|MAP_FIXED|MAP_DENYWRITE, 3, 0x1f000) = 0x7f10e7f2b000
mmap(0x7f10e7f34000, 8192, PROT_READ|PROT_WRITE, MAP_PRIVATE|MAP_FIXED|MAP_DENYWRITE, 3, 0x27000) = 0x7f10e7f34000
close(3)                                = 0
openat(AT_FDCWD, "/lib/x86_64-linux-gnu/libstdc++.so.6", O_RDONLY|O_CLOEXEC) = 3
read(3, "\177ELF\2\1\1\3\0\0\0\0\0\0\0\0\3\0>\0\1\0\0\0\240\341\t\0\0\0\0\0"..., 832) = 832
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

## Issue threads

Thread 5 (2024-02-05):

L3: R1 and R3 swapped on the PCB

yarda, 2024-02-05:
What's marked as R1 in the schematic is marked as R3 on the L3 PCB and vice versa.

Also I think that R1 (in the schematic) can be dropped which would result in higher brightness of the LED and lower power consumption (cca. 50 %). I guess the R1 is only there to tolerate arbitrary LED orientation / polarity.

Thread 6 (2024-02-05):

L3: VSSOP-8 LM555 footprint used on the PCB instead of the TSSOP-8 making it real challenge to solder

yarda, 2024-02-05:
Currently, LM555 or compatible in VSSOP-8 is nearly impossible to obtain. Almost all available LM555 chips are TSSOP-8 and this is what you also shipped on your events. Taking into account the VSSOP-8 footprint is narrower than the TSSOP-8 chip it's a real challenge to correctly solder the chip. This probably wasn't the original intention of this challenge :).

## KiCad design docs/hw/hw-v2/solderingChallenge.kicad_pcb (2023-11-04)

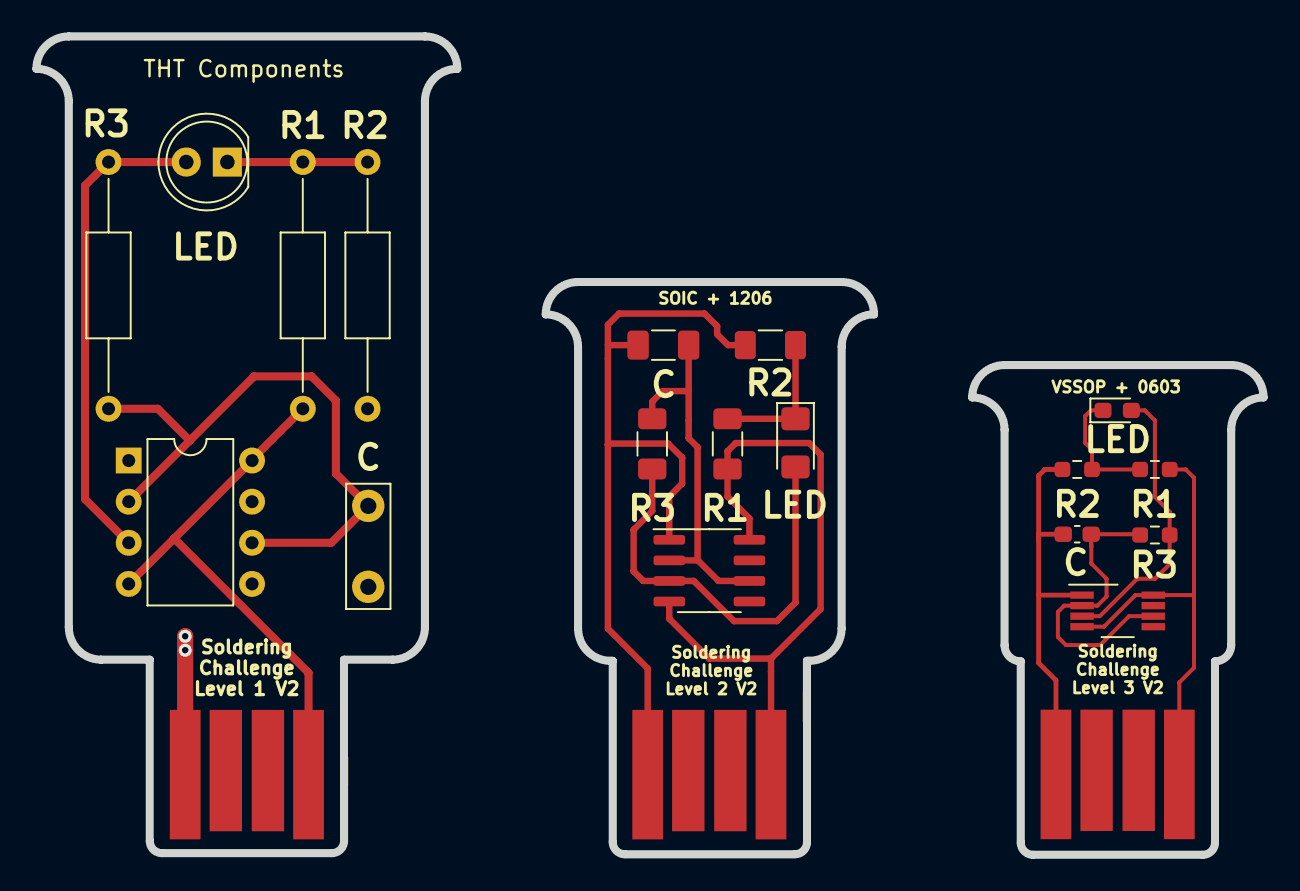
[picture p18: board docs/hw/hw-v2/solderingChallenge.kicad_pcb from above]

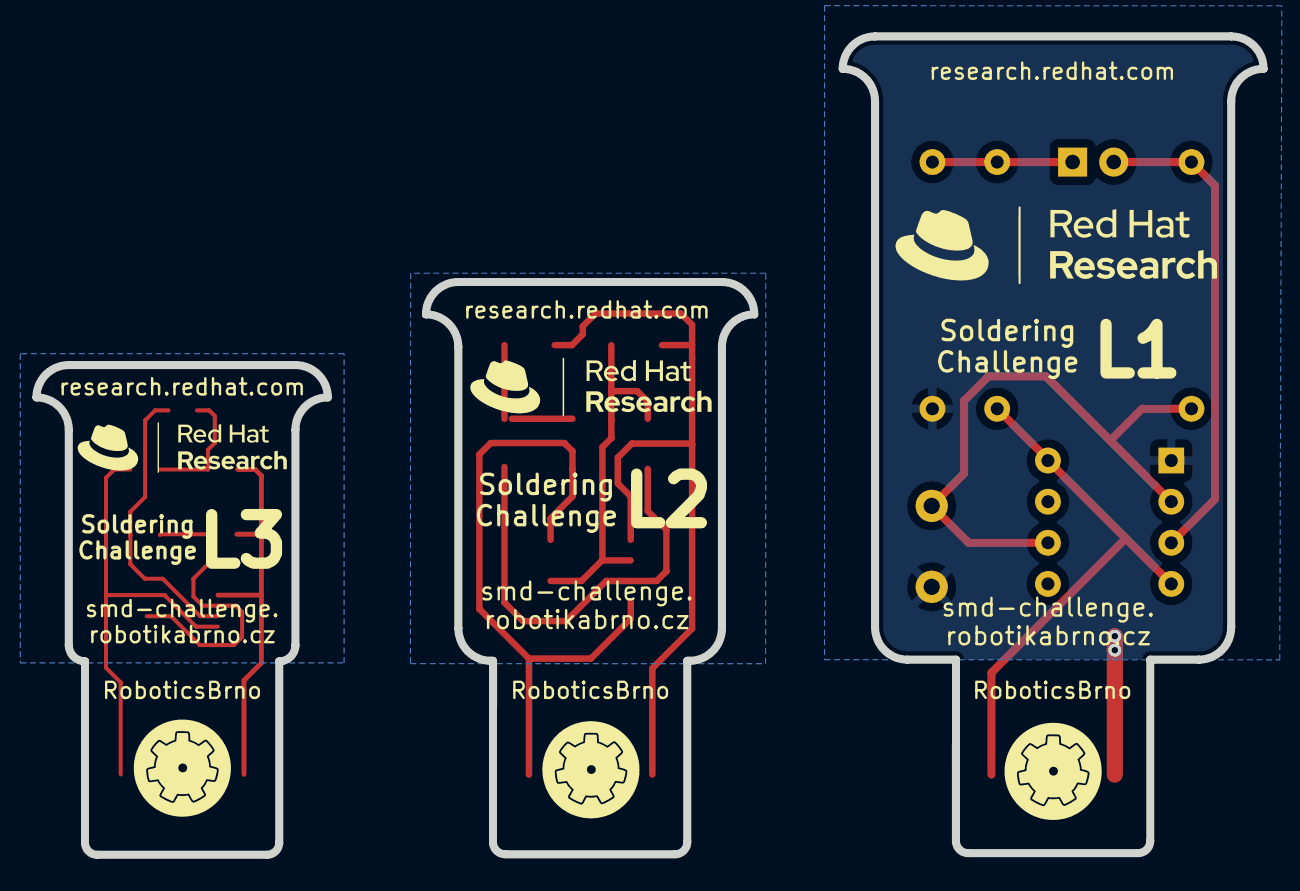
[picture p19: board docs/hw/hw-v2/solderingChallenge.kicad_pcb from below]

Board: 2 copper layers, 75.8 x 50.6 mm, 24 parts (3 on the bottom side), 12 nets.

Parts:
C1: 1u; C_Disc_D7.5mm_W2.5mm_P5.00mm
C1#2: 1uF; C_0603_1608Metric_Pad1.08x0.95mm_HandSolder
C2: 1u; C_1206_3216Metric_Pad1.33x1.80mm_HandSolder
D1: LED; LED_D5.0mm
D2: LED; LED_1206_3216Metric_Pad1.42x1.75mm_HandSolder
D3: LED; LED_0603_1608Metric_Pad1.05x0.95mm_HandSolder
J2: USB_A; usb-PCB
Kolecko1, Kolecko1#2, Kolecko1#3: robotarnaLogo; RobotarnaLogo-6mm
R1, R3: 470; R_Axial_DIN0207_L6.3mm_D2.5mm_P15.24mm_Horizontal
R2: 1M; R_0603_1608Metric_Pad0.98x0.95mm_HandSolder
R2#2: 1M; R_Axial_DIN0207_L6.3mm_D2.5mm_P15.24mm_Horizontal
R3#2, R5: 470R; R_1206_3216Metric_Pad1.30x1.75mm_HandSolder
R4: 1M; R_1206_3216Metric_Pad1.30x1.75mm_HandSolder
R5#2, R6: 470; R_0603_1608Metric_Pad0.98x0.95mm_HandSolder
U1: LM555xN; DIP-8_W7.62mm
U2: LMC555xM; SOIC-8_3.9x4.9mm_P1.27mm
U3: LMC555xMM; VSSOP-8_3.0x3.0mm_P0.65mm
U6, U8: USB_A; usb-PCB

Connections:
/Level 1 - THT/GND: C1.2, J2.4 (GND), R3.2, U1.1 (GND)
/Level 1 - THT/VCC: J2.1 (VBUS), R1.1, U1.4 (R), U1.8 (VCC)
/Level 2 - 1206/GND: C2.2, R3#2.1, U2.1 (GND), U6.4 (GND)
/Level 2 - 1206/VCC: R5.2, U2.4 (R), U2.8 (VCC), U6.1 (VBUS)
/Level 3 - 0603/GND: C1#2.2, R6.2, U3.1 (GND), U8.4 (GND)
/Level 3 - 0603/VCC: R5#2.1, U3.4 (R), U3.8 (VCC), U8.1 (VBUS)
unnamed: C1.1, R2#2.1, U1.2 (TR), U1.6 (THR)
unnamed: D1.1 (K), R1.2, R3.1
unnamed: D1.2 (A), R2#2.2, U1.3 (Q)
unnamed: D2.1 (K), R3#2.2, R5.1
unnamed: D2.2 (A), R4.2, U2.3 (Q)
unnamed: D3.1 (K), R5#2.2, R6.1

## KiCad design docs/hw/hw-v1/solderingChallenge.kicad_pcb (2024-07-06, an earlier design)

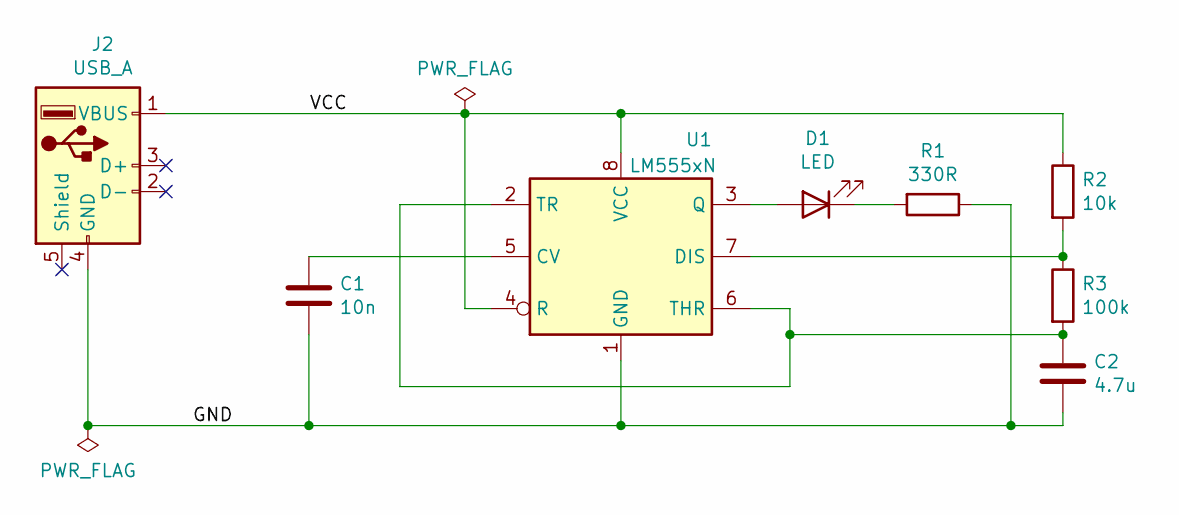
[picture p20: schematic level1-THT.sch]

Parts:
C1: 10n; C_Disc_D6.0mm_W2.5mm_P5.00mm
C2: 4.7u; C_Disc_D6.0mm_W2.5mm_P5.00mm
D1: LED; LED_D5.0mm
J2: USB_A; usb-PCB
R1: 330R; R_Axial_DIN0204_L3.6mm_D1.6mm_P5.08mm_Horizontal
R2: 10k; R_Axial_DIN0204_L3.6mm_D1.6mm_P5.08mm_Horizontal
R3: 100k; R_Axial_DIN0204_L3.6mm_D1.6mm_P5.08mm_Horizontal
U1: LM555xN; DIP-8_W7.62mm

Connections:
/Level 1 - THT/GND: C1.2, C2.2, J2.4 (GND), R1.1, U1.1 (GND)
/Level 1 - THT/VCC: J2.1 (VBUS), R2.1, U1.4 (R), U1.8 (VCC)
unnamed: C1.1, U1.5 (CV)
unnamed: C2.1, R3.2, U1.2 (TR), U1.6 (THR)
unnamed: D1.1 (K), R1.2
unnamed: D1.2 (A), U1.3 (Q)
unnamed: R2.2, R3.1, U1.7 (DIS)

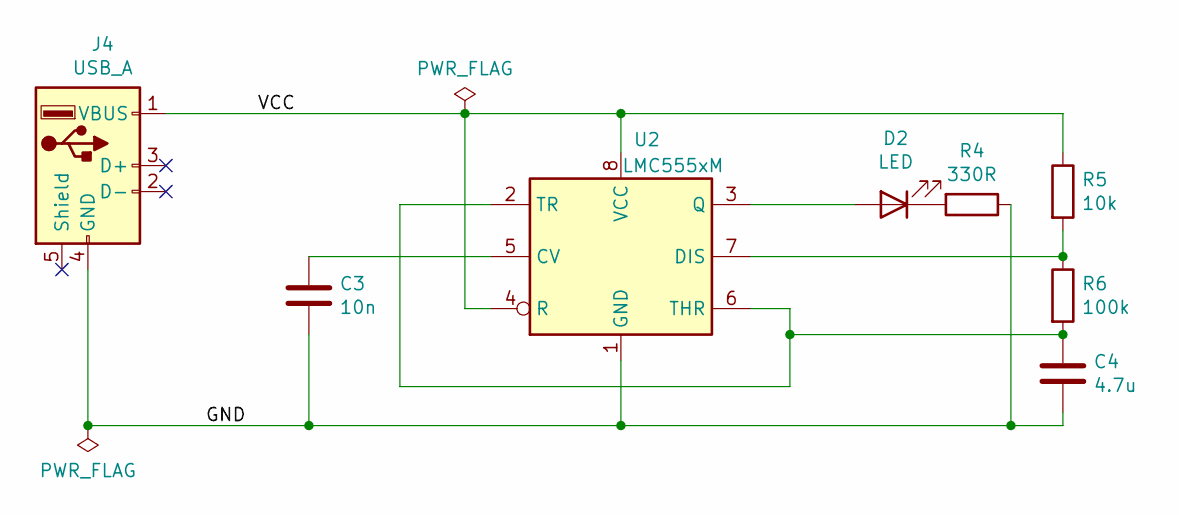
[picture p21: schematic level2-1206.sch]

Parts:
C3: 10n; C_1206_3216Metric_Pad1.42x1.75mm_HandSolder
C4: 4.7u; C_1206_3216Metric_Pad1.42x1.75mm_HandSolder
D2: LED; LED_1206_3216Metric_Pad1.42x1.75mm_HandSolder
J4: USB_A; usb-PCB
R4: 330R; R_1206_3216Metric_Pad1.42x1.75mm_HandSolder
R5: 10k; R_1206_3216Metric_Pad1.42x1.75mm_HandSolder
R6: 100k; R_1206_3216Metric_Pad1.42x1.75mm_HandSolder
U2: LMC555xM; SOIC-8_3.9x4.9mm_P1.27mm

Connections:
/Level 2 - 1206/GND: C3.2, C4.2, J4.4 (GND), R4.1, U2.1 (GND)
/Level 2 - 1206/VCC: J4.1 (VBUS), R5.1, U2.4 (R), U2.8 (VCC)
unnamed: C3.1, U2.5 (CV)
unnamed: C4.1, R6.2, U2.2 (TR), U2.6 (THR)
unnamed: D2.1 (K), R4.2
unnamed: D2.2 (A), U2.3 (Q)
unnamed: R5.2, R6.1, U2.7 (DIS)

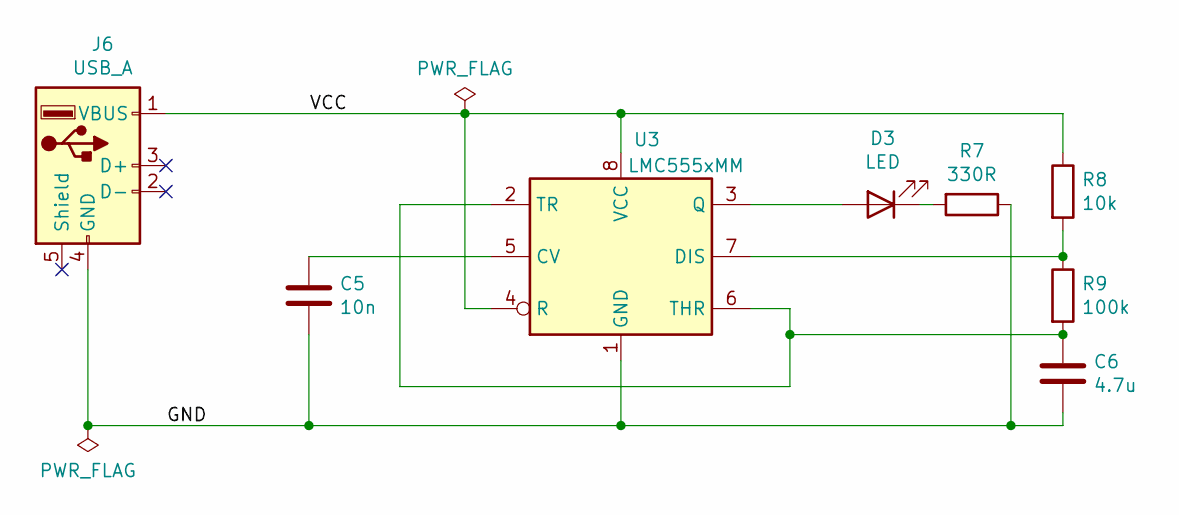
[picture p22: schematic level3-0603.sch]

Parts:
C5: 10n; C_0603_1608Metric_Pad1.05x0.95mm_HandSolder
C6: 4.7u; C_0603_1608Metric_Pad1.05x0.95mm_HandSolder
D3: LED; LED_0603_1608Metric_Pad1.05x0.95mm_HandSolder
J6: USB_A; usb-PCB
R7: 330R; R_0603_1608Metric_Pad1.05x0.95mm_HandSolder
R8: 10k; R_0603_1608Metric_Pad1.05x0.95mm_HandSolder
R9: 100k; R_0603_1608Metric_Pad1.05x0.95mm_HandSolder
U3: LMC555xMM; VSSOP-8_3.0x3.0mm_P0.65mm

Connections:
/Level 3 - 0603/GND: C5.2, C6.2, J6.4 (GND), R7.1, U3.1 (GND)
/Level 3 - 0603/VCC: J6.1 (VBUS), R8.1, U3.4 (R), U3.8 (VCC)
unnamed: C5.1, U3.5 (CV)
unnamed: C6.1, R9.2, U3.2 (TR), U3.6 (THR)
unnamed: D3.1 (K), R7.2
unnamed: D3.2 (A), U3.3 (Q)
unnamed: R8.2, R9.1, U3.7 (DIS)

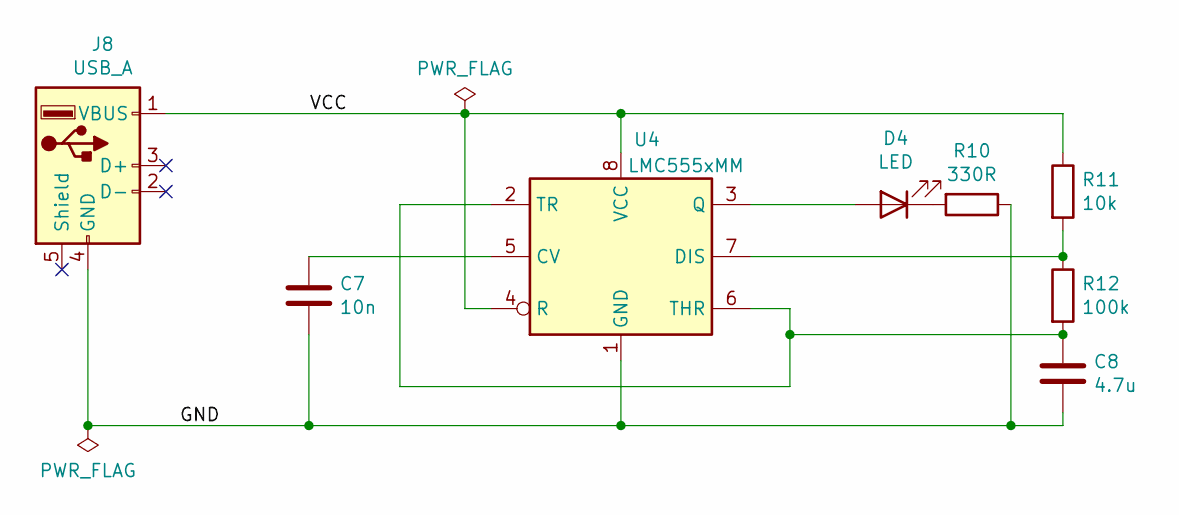
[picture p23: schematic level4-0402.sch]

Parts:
C7: 10n; C_0402_1005Metric
C8: 4.7u; C_0402_1005Metric
D4: LED; LED_0402_1005Metric
J8: USB_A; usb-PCB
R10: 330R; R_0402_1005Metric
R11: 10k; R_0402_1005Metric
R12: 100k; R_0402_1005Metric
U4: LMC555xMM; VSSOP-8_3.0x3.0mm_P0.65mm

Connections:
/Level 4 - 0402/GND: C7.2, C8.2, J8.4 (GND), R10.1, U4.1 (GND)
/Level 4 - 0402/VCC: J8.1 (VBUS), R11.1, U4.4 (R), U4.8 (VCC)
unnamed: C7.1, U4.5 (CV)
unnamed: C8.1, R12.2, U4.2 (TR), U4.6 (THR)
unnamed: D4.1 (K), R10.2
unnamed: D4.2 (A), U4.3 (Q)
unnamed: R11.2, R12.1, U4.7 (DIS)

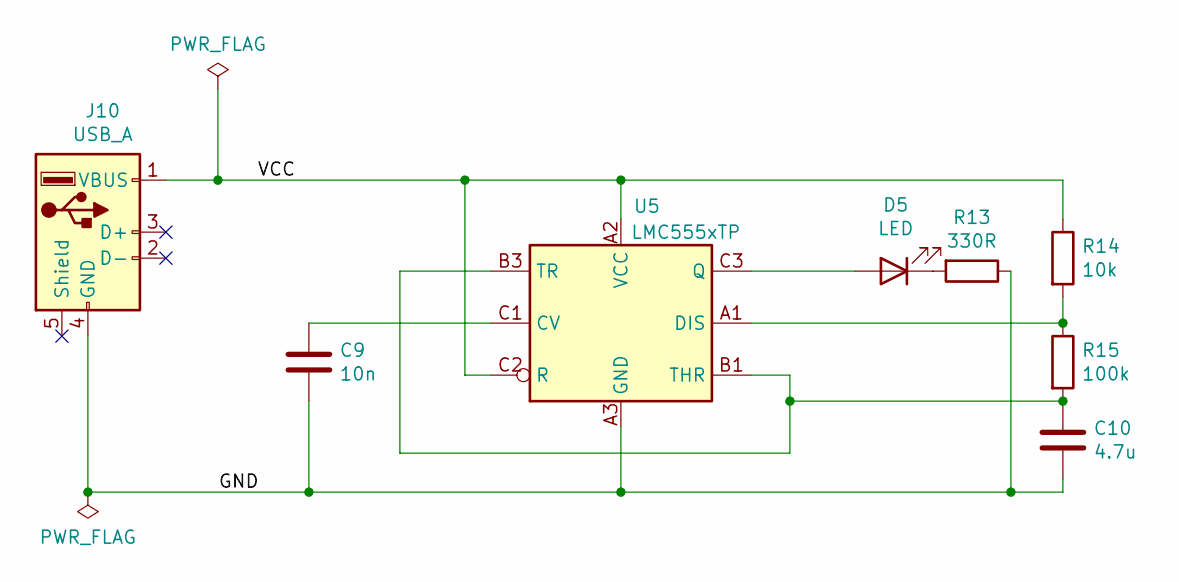
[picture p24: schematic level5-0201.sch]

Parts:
C9: 10n; C_0201_0603Metric
C10: 4.7u; C_0201_0603Metric
D5: LED; LED_0201_0603Metric
J10: USB_A; usb-PCB
R13: 330R; R_0201_0603Metric
R14: 10k; R_0201_0603Metric
R15: 100k; R_0201_0603Metric
U5: LMC555xTP; Texas_DSBGA-8_1.43x1.41mm_Layout3x3_P0.5mm

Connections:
/Level 5 - 0201/GND: C9.2, C10.2, J10.4 (GND), R13.1, U5.A3 (GND)
/Level 5 - 0201/VCC: J10.1 (VBUS), R14.1, U5.A2 (VCC), U5.C2 (R)
unnamed: C9.1, U5.C1 (CV)
unnamed: C10.1, R15.2, U5.B1 (THR), U5.B3 (TR)
unnamed: D5.1 (K), R13.2
unnamed: D5.2 (A), U5.C3 (Q)
unnamed: R14.2, R15.1, U5.A1 (DIS)

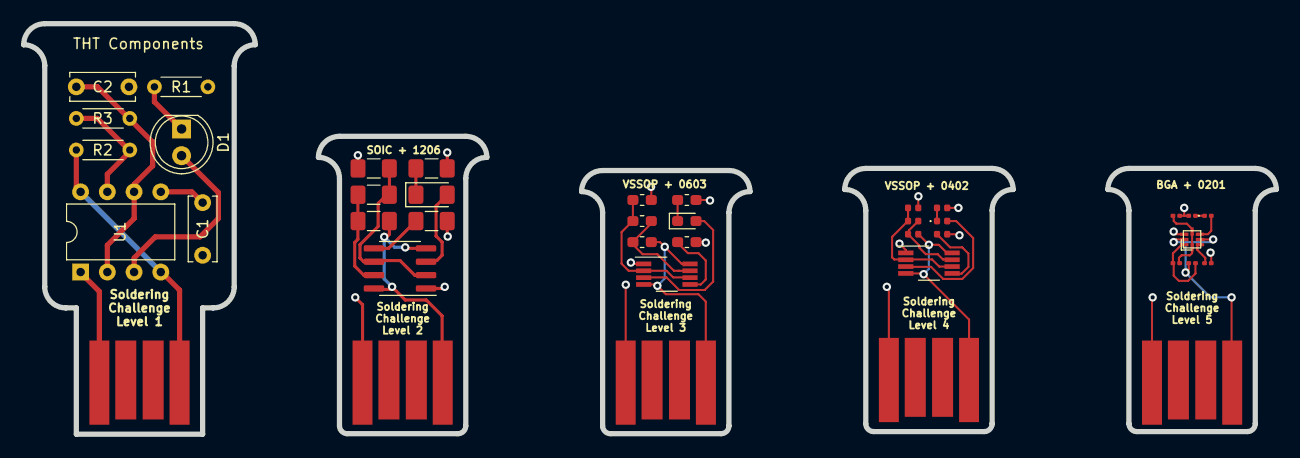
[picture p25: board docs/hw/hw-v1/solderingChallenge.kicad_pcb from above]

Board: 2 copper layers, 119.0 x 39.0 mm, 40 parts (0 on the bottom side), 35 nets.

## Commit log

2023-02-03 Aesthetics
    - resizing levels 2 and 3
    - centering 555
    - create the same labels for the same parts in all levels
    [solderingChallenge.kicad_pcb]
2023-05-12 level 1
    [level1-THT.kicad_sch, solderingChallenge.kicad_pcb, solderingChallenge.kicad_sch]
2023-05-12 Level 2 and 3
    [level1-THT.kicad_sch, level2-1206.kicad_sch, level3-0603.kicad_sch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]
2023-09-23 Documentation Schematics
2023-10-04 Update assembly, add video plugin, new team info
2023-10-11 Add soldering info, update team
2023-10-23 Resistor labels
    [level1-THT.kicad_sch, solderingChallenge.kicad_pcb, solderingChallenge.kicad_sch]
2023-11-04 Fix .gitignore
    [solderingChallenge.kicad_pcb]
2024-07-06 Add version 1, update to work with multiple versions
    [leve4-alt-0402.sch, level1-THT.kicad_sch, level1-THT.sch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]
2025-07-02 Update image paths and sizes in soldering instructions
